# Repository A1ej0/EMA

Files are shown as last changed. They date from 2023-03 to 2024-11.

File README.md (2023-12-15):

<div align="center">

</div>  

# <div align="center">EMA - Estación de Monitoreo Automático 🍃</div>  

<div align="right">
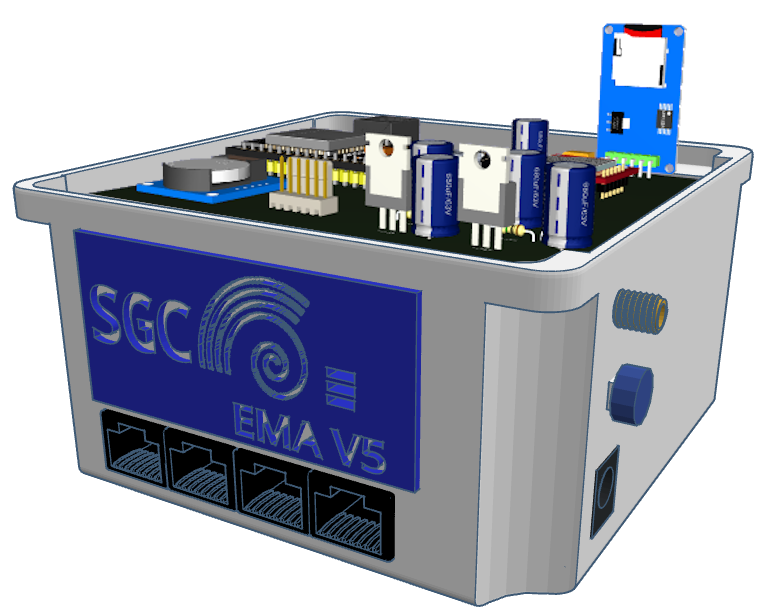
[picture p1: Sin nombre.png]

</div>  

-  De bajo costo💸  

- Enfoque comunitario 🙆🧑‍🎓🧑‍🌾🧑‍🍳🧑‍🚒  

- De alta tecnologia 🚀🛸  

<br/>  

## Que es?  
EMA nace con el objetivo de brindar una alternativa con un sentido social y un enfoque comunitario a dispositivos tecnológicos de alto coste y complejidad, brindando la oportunidad a la comunidad de participar en temas relacionados a la medición de variables medioambientales para el monitoreo de diferentes factores como lluvias, movimientos del suelo, crecimiento de los ríos y calidad de agua. 🌋🏔️🏞️

Todo esto a muy bajo coste y una construcción modular, con partes de muy fácil obtención para promover la participación de todo el mundo 
🌎  

<br/>  

## Que incluye?  
<div align="center">  
<a href="https://pytorch.org/" target="_blank">pytorch</a>  
<a href="https://www.python.org/" target="_blank">Python</a>  
<a href="https://www.cprogramming.com/" target="_blank">C</a>  
<a href="https://www.cplusplus.com/" target="_blank">C++</a>  
<a href="https://www.javascript.com/" target="_blank">JavaScript</a>  
</div>  

El proyecto EMA esta diseñado con un enfoque de codigo abierto y software libre, es por esto que se usaron lenguajes de programacion y aplicativos con este enfoque, para el modulo principal que incluye la placa principal del proyecto (ESP32), se uso micropython, para los sensores externos que requieren un microcontrolador para ser interpretados se uso C++ como codigo de programacion, para la interface web, se hizo uso de Node-red, proyecto de codigo abierto creado por IBM y finalmente Mosquitto como broker de MQTT  

<br/>  

## Características  
- ### Conexión ✨  

📶 Bluetooth, Diseñado para lectura, ajuste y extracción de información desde dispositivos móviles

🥝Wifi, Diseñado para el envió de lecturas de los sensores al servidor del proyecto

📱GPRS, Diseñado para el envió de lectura de sensores mediante una red móvil en caso de ausencia de wifi

📝MicroSD, diseñada para almacenar de forma local lectura de sensores en caso de ausencia de cualquier lectura y como forma de llevar registros

- ### Módulos 🧩  

Los módulos son los sensores que es capaz de leer EMA  

⛈️ Pluviómetro, modulo diseñado para leer los niveles de lluvia en la zona

📏 Distancia, modulo diseñado con ultrasonido para medir distancias de niveles de ríos o similares

🏜️ Temperatura, Modulo diseñado para medir la temperatura medio ambiental

🚄 Aceleración, Modulo diseñado para medir el movimiento de los suelos, montañas, etc

⌛ Reloj, Modulo diseñado para llevar un registro de tiempo del momento de toma de lecturas

💧Calidad de agua, Modulo diseñado para medir el nivel de contaminación de ríos o cuerpos de agua  

- ### Proyección 🚀✨  

Se espera para el futuro la integración de módulos adicionales para lecturas de variables medioambientales diferentes con una variedad mas amplia de sensores, también se pretende el diseño y construcción de un sistema de programación remoto por medio del cual los usuarios podrán cargar el programa en la placa de desarrollo sin requerir ningún programa mas allá de un navegador web 💻  

<br />

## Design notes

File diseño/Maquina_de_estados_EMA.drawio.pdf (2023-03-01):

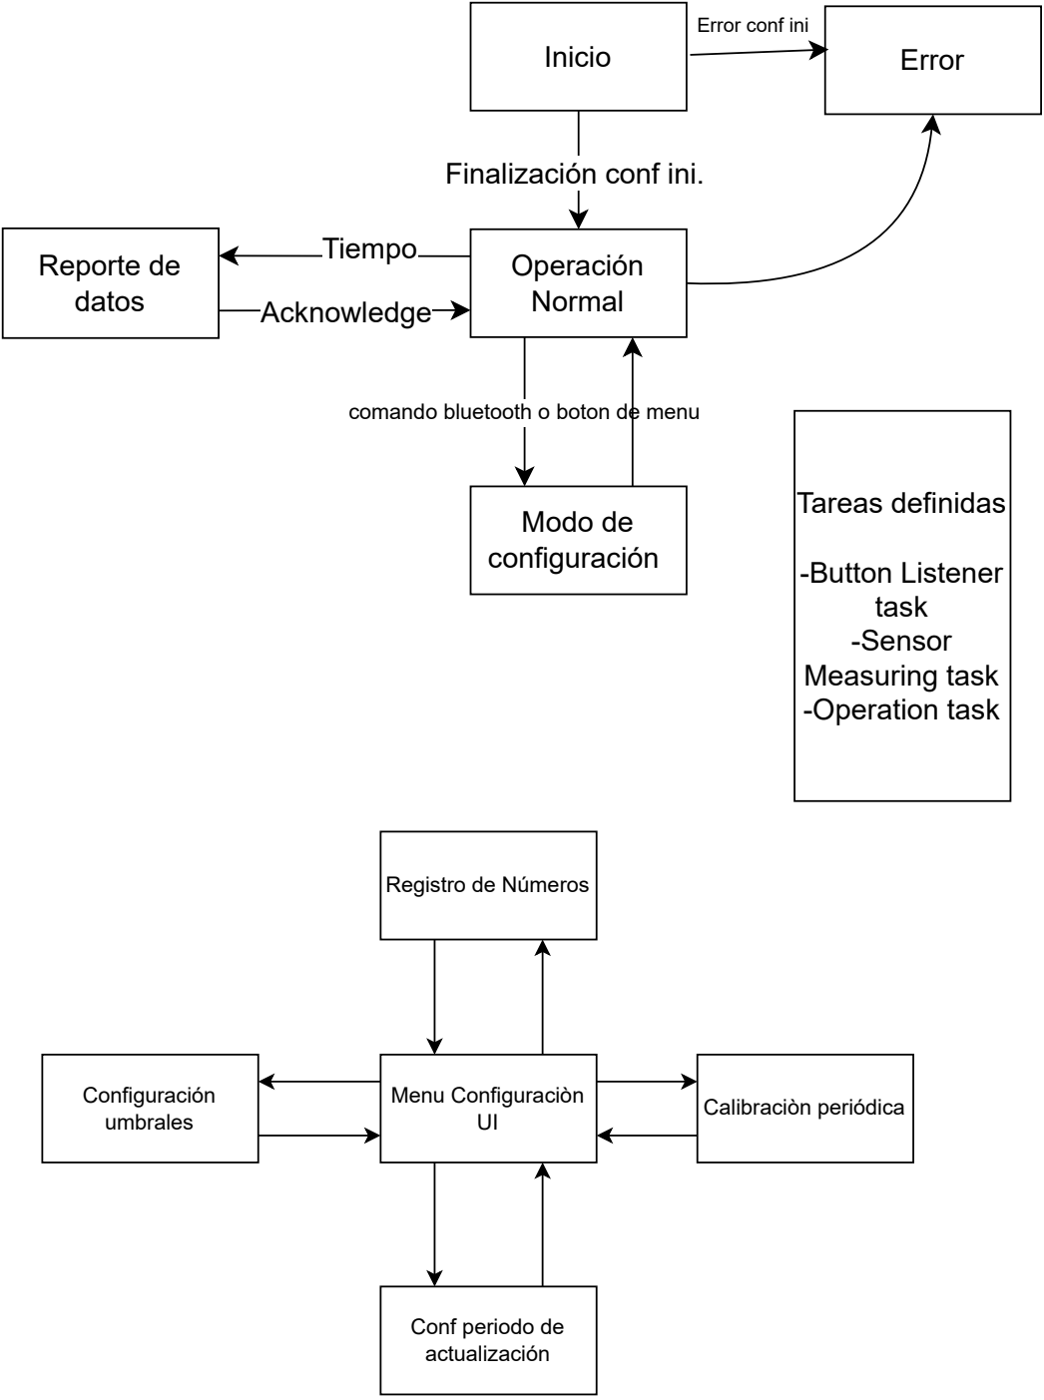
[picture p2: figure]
Inicio; Operación Normal; Finalización conf ini.; Modo de configuración; comando bluetooth o boton de menu; Reporte de datos; Tiempo; Acknowledge; Tareas definidas; -Button Listener task -Sensor Measuring task -Operation task; Error; Error conf ini; Menu Configuraciòn; Calibraciòn periódica Configuración; umbrales; Registro de Números; Conf periodo de actualización

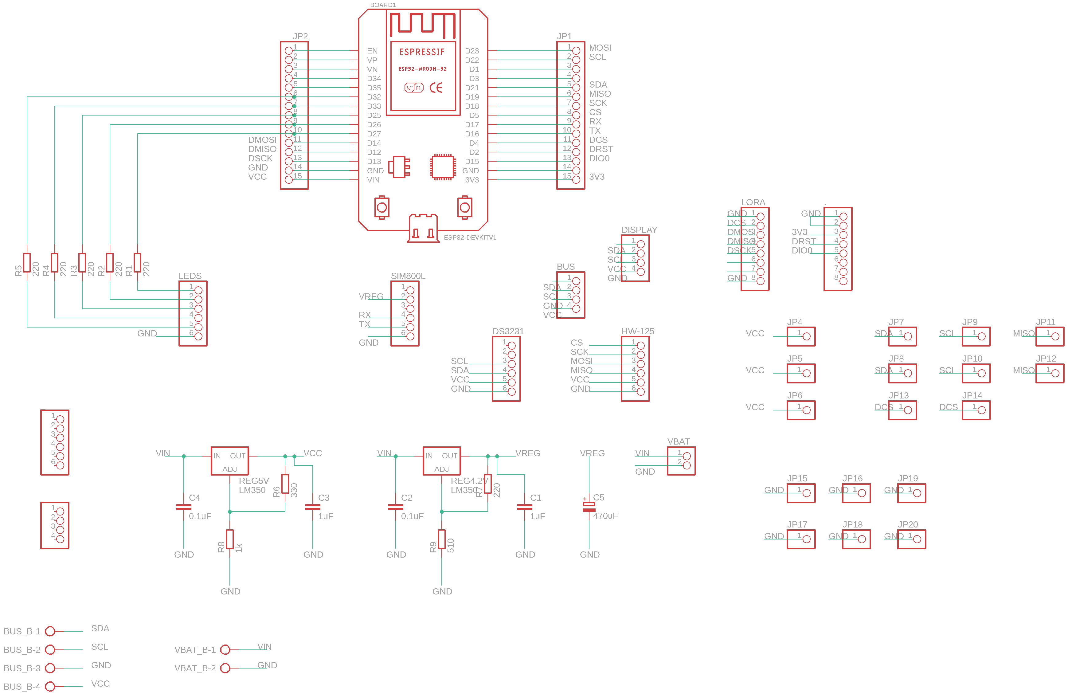
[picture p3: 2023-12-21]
PCB_EMA/EMA_4/schematic.png

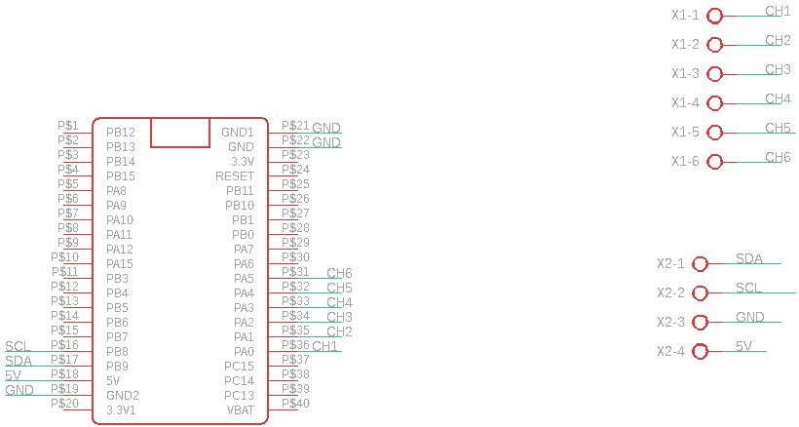
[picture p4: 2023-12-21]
PCB_EMA/EMA_BLUEPILL_MODULE/schematic.png

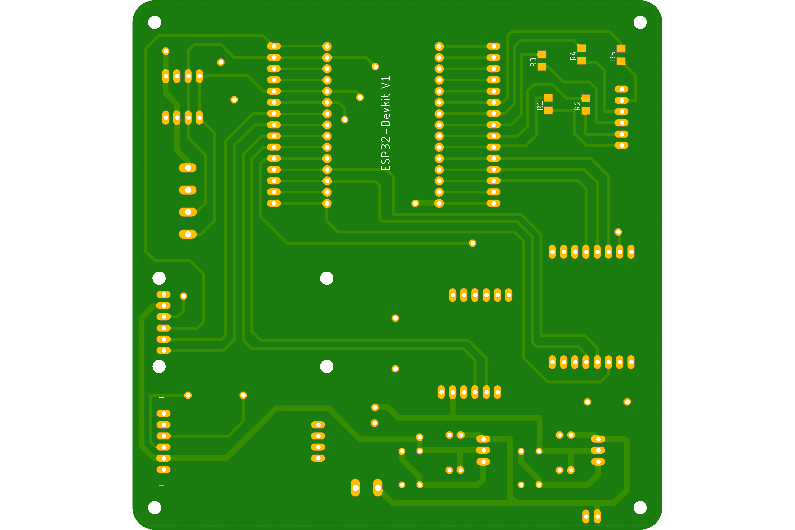
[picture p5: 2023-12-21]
PCB_EMA/EMA_4/board_.png

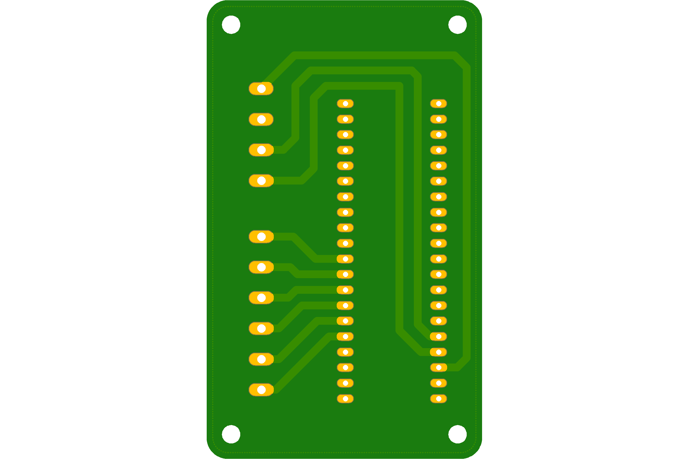
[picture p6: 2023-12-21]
PCB_EMA/EMA_BLUEPILL_MODULE/ema-module2.png

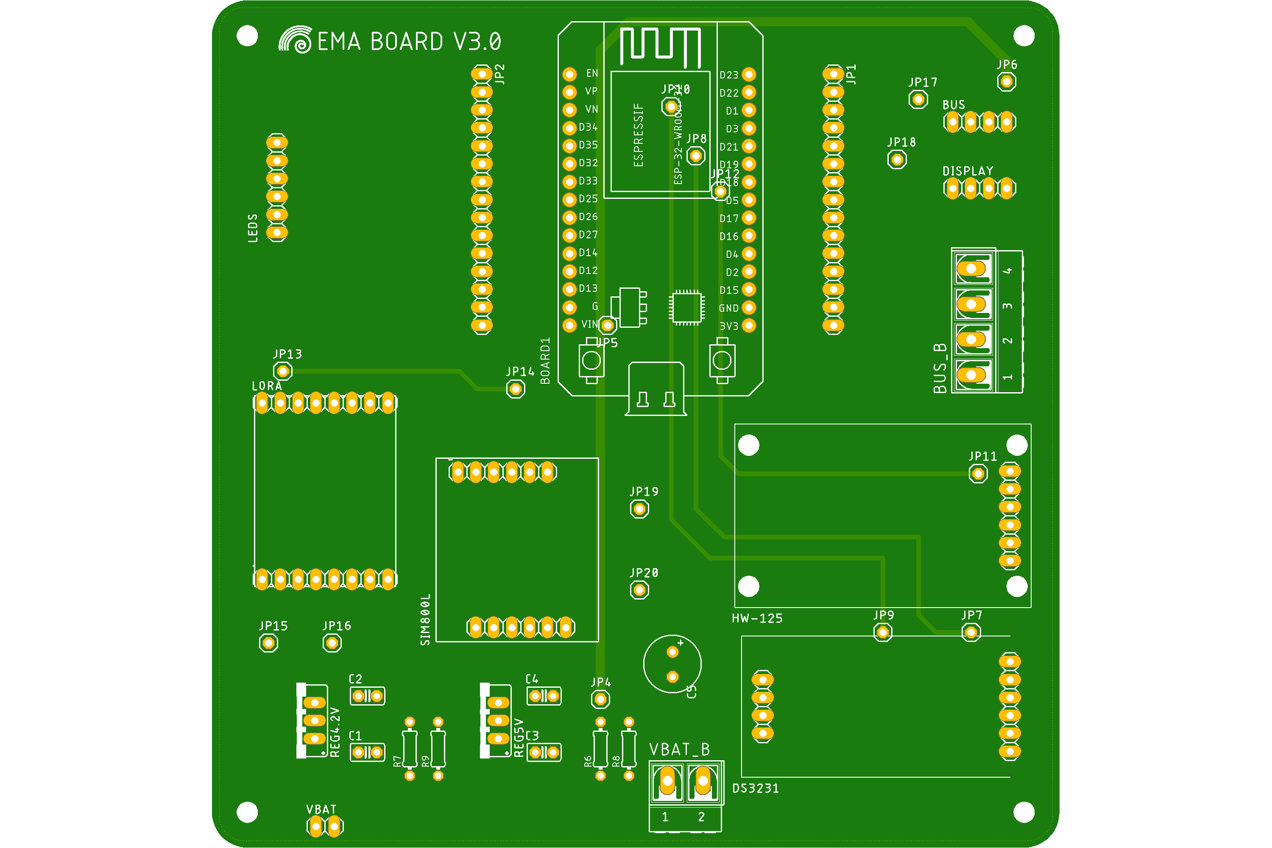
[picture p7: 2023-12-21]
PCB_EMA/EMA_4/board.png

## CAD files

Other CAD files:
Ahorro Sensores/startup.obj
Ahorro Sensores/ahorro.obj

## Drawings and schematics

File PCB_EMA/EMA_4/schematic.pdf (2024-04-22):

3V3_EN | 37 GND | 3*8
VSYS | 39 VBUS | 40 SWDIO 43 | SWGND 42 | SWCLK 41

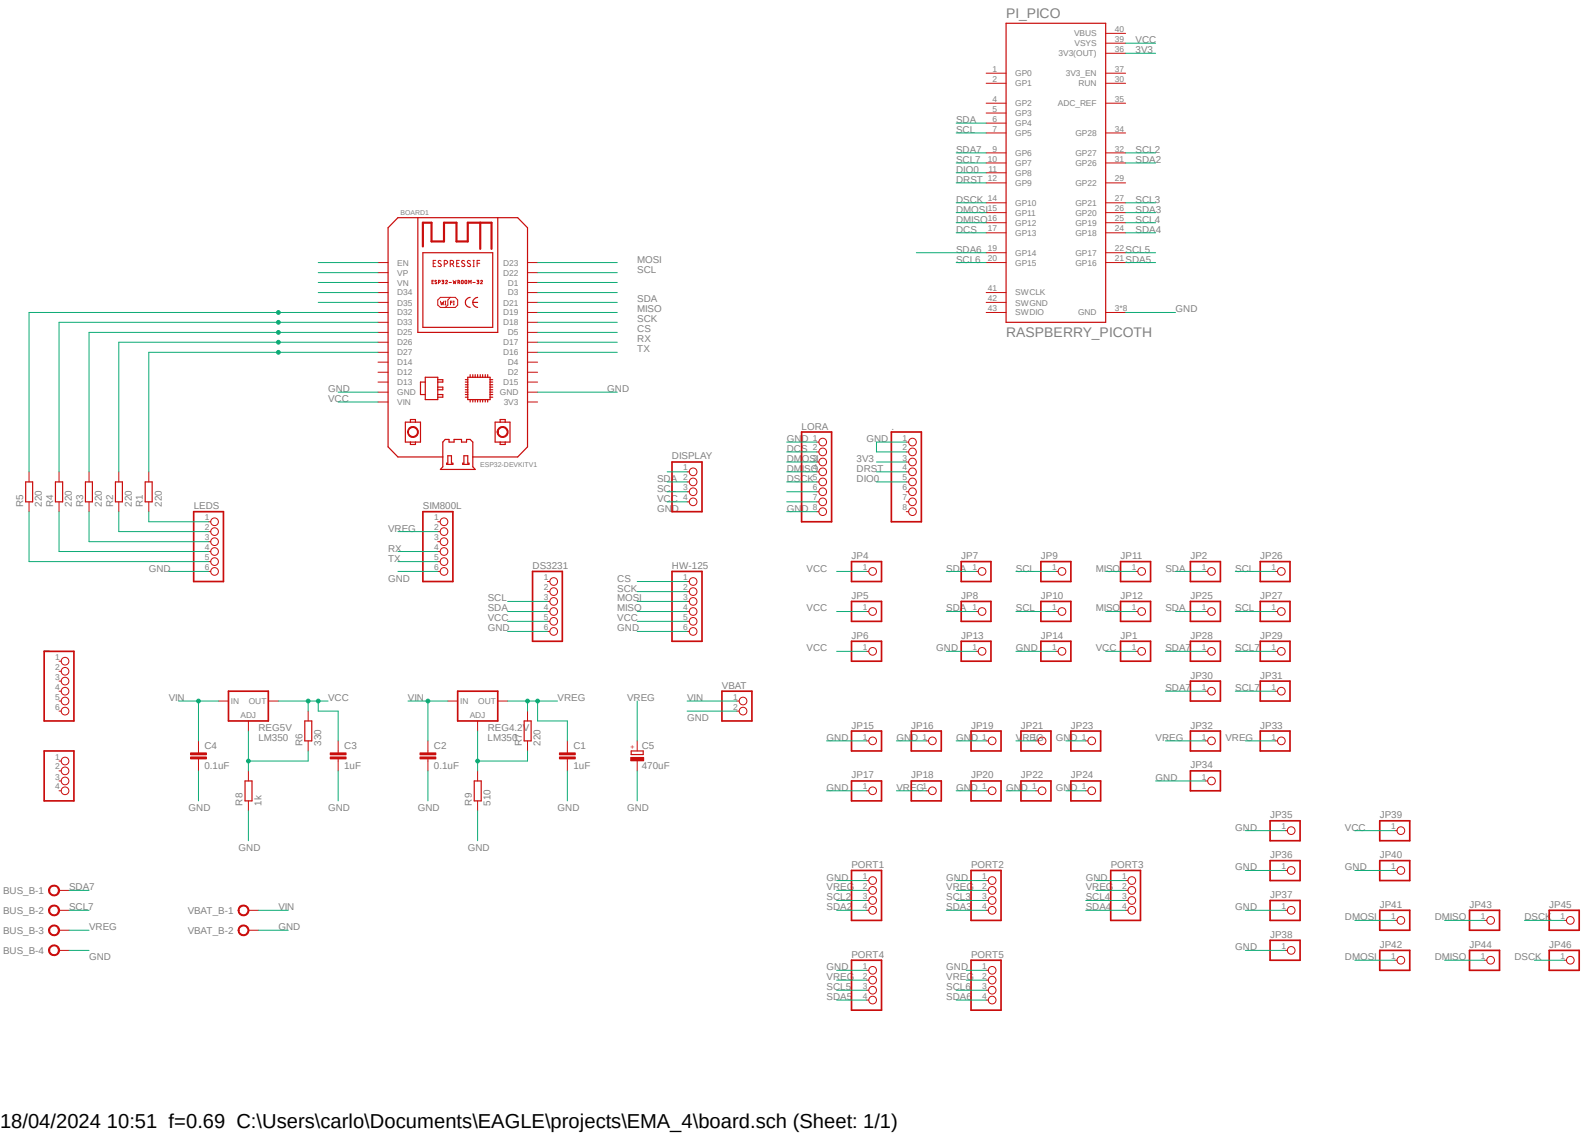
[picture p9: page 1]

18/04/2024 10:51 f=0.69 C:\Users\carlo\Documents\EAGLE\projects\EMA_4\board.sch (Sheet: 1/1)

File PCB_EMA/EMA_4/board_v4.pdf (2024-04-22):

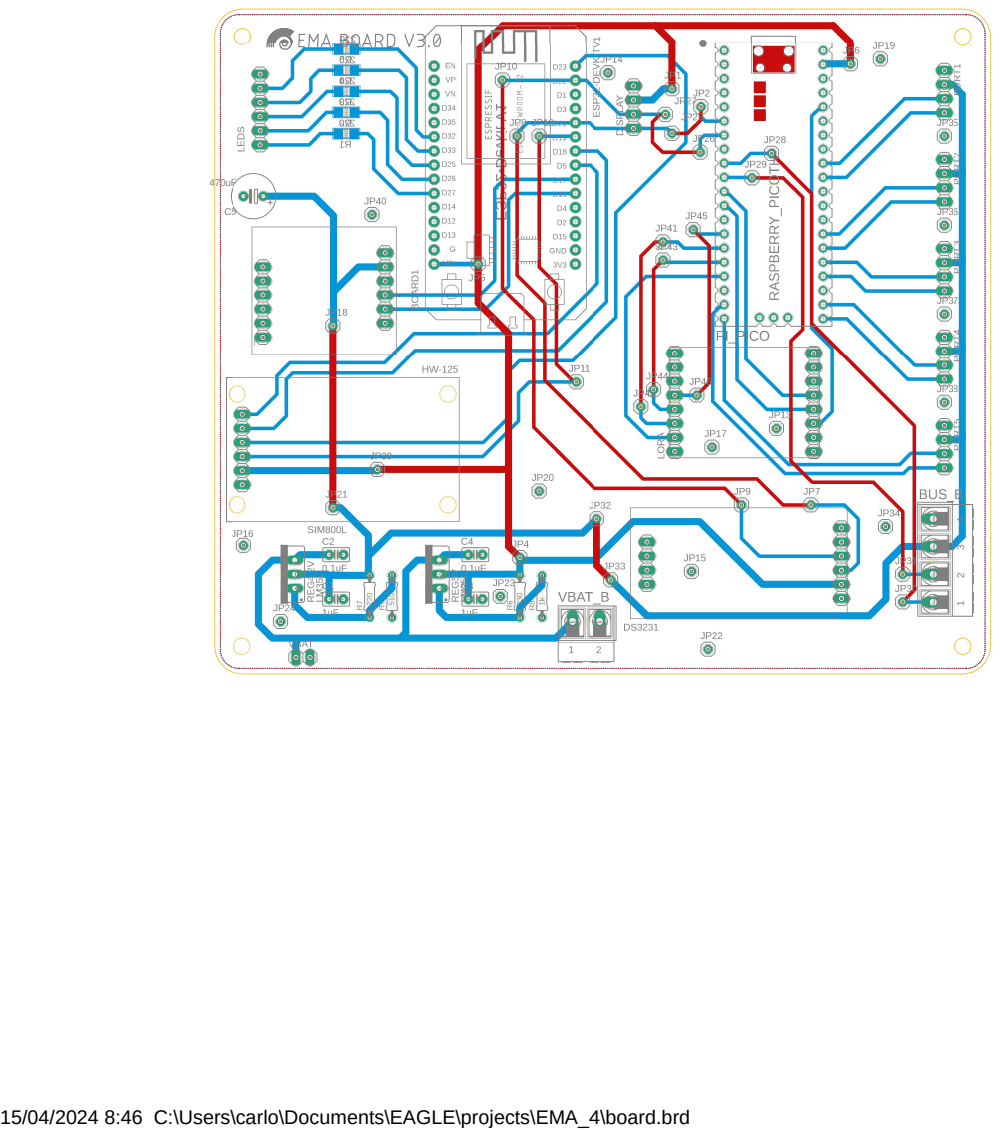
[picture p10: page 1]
PORT1 PORT4 PORT2 PORT5 PORT3

15/04/2024 8:46 C:\Users\carlo\Documents\EAGLE\projects\EMA_4\board.brd

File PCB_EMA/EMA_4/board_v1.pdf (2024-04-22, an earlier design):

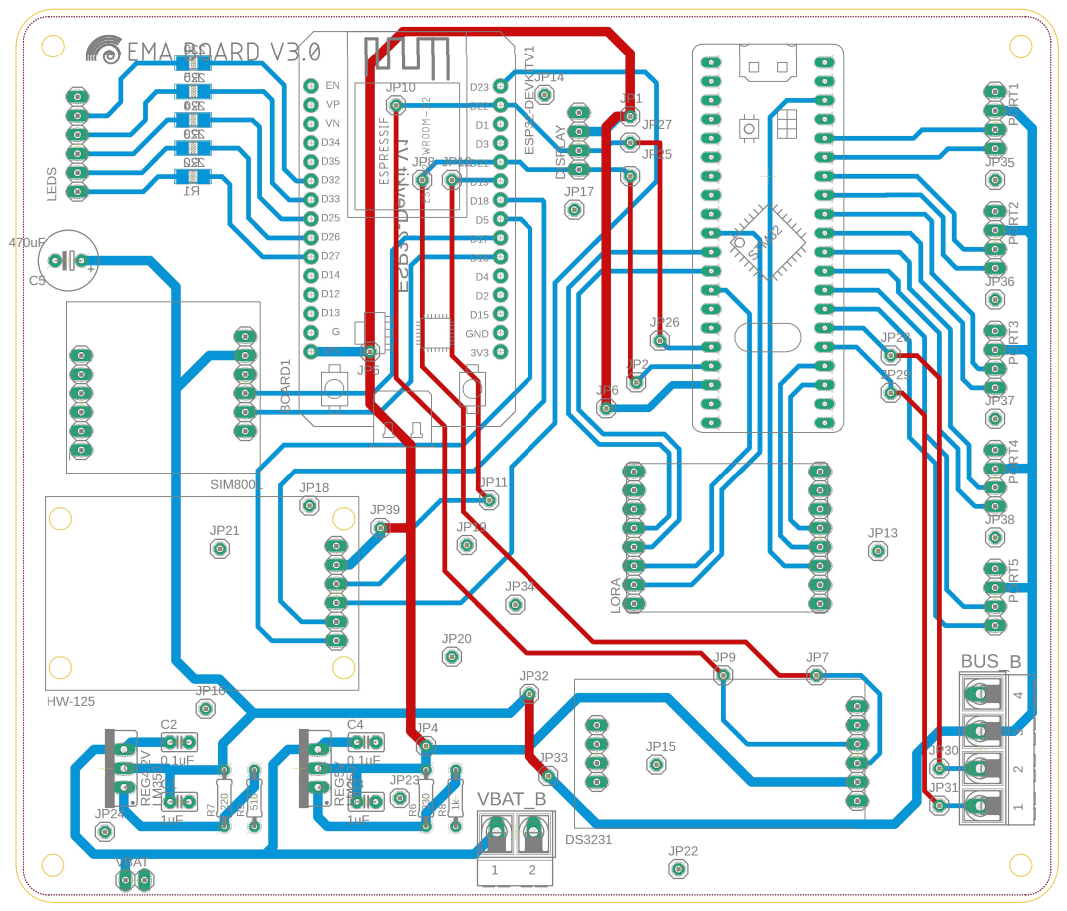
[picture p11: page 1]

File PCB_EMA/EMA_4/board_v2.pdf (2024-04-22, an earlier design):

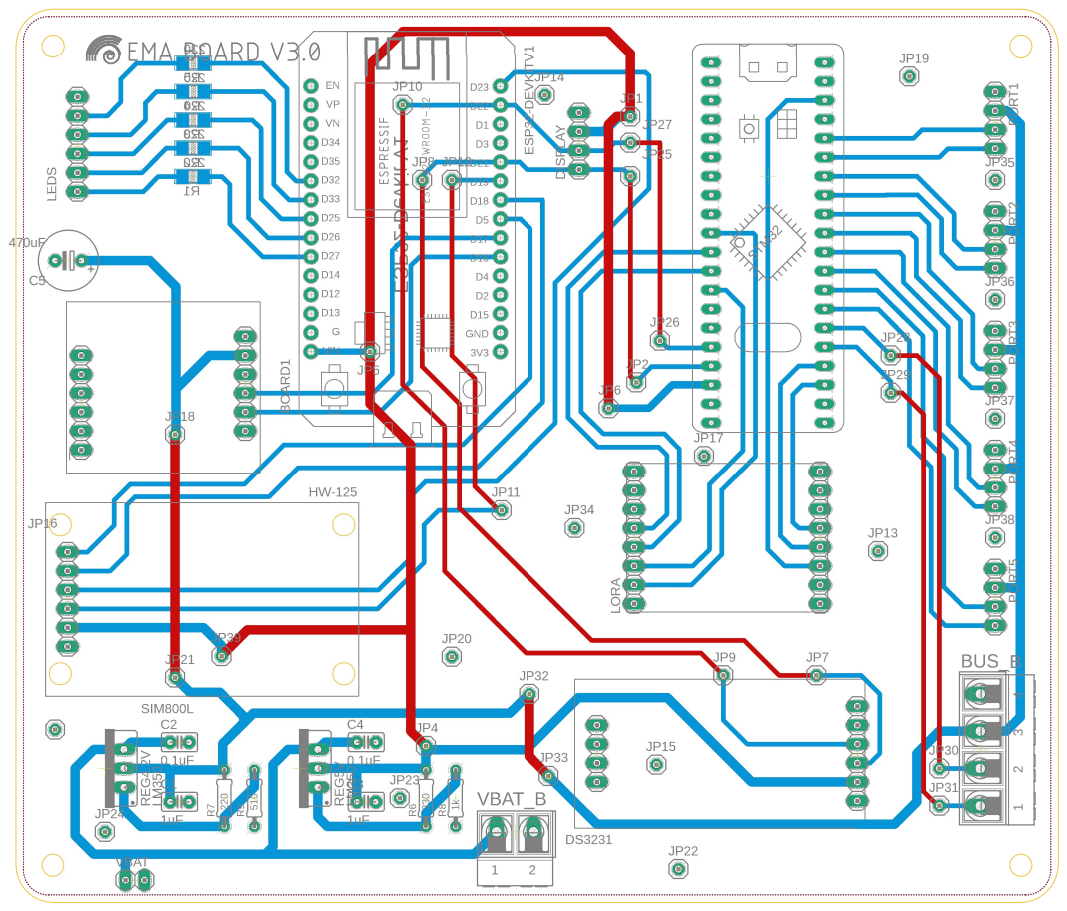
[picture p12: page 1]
PORT1 PORT4 PORT2 PORT5 PORT3

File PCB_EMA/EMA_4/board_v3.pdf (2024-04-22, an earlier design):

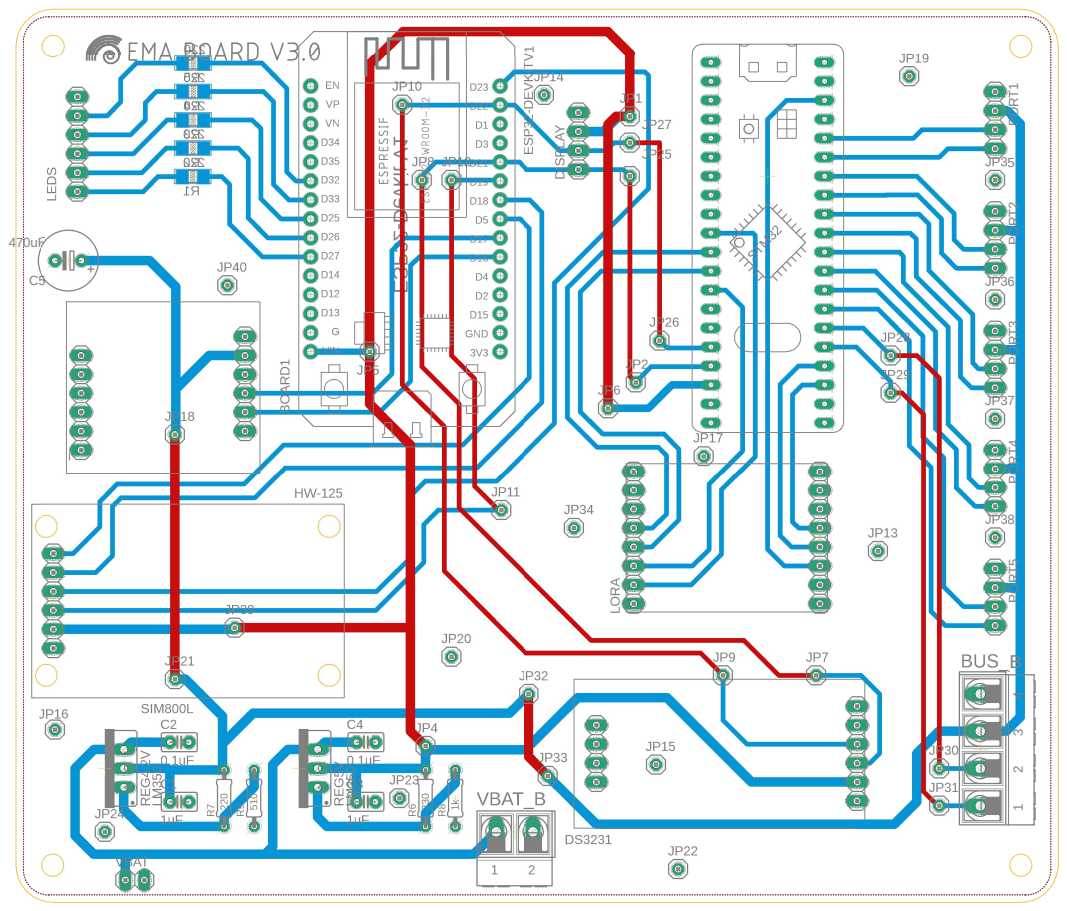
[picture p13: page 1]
PORT1 PORT4 PORT2 PORT5 PORT3

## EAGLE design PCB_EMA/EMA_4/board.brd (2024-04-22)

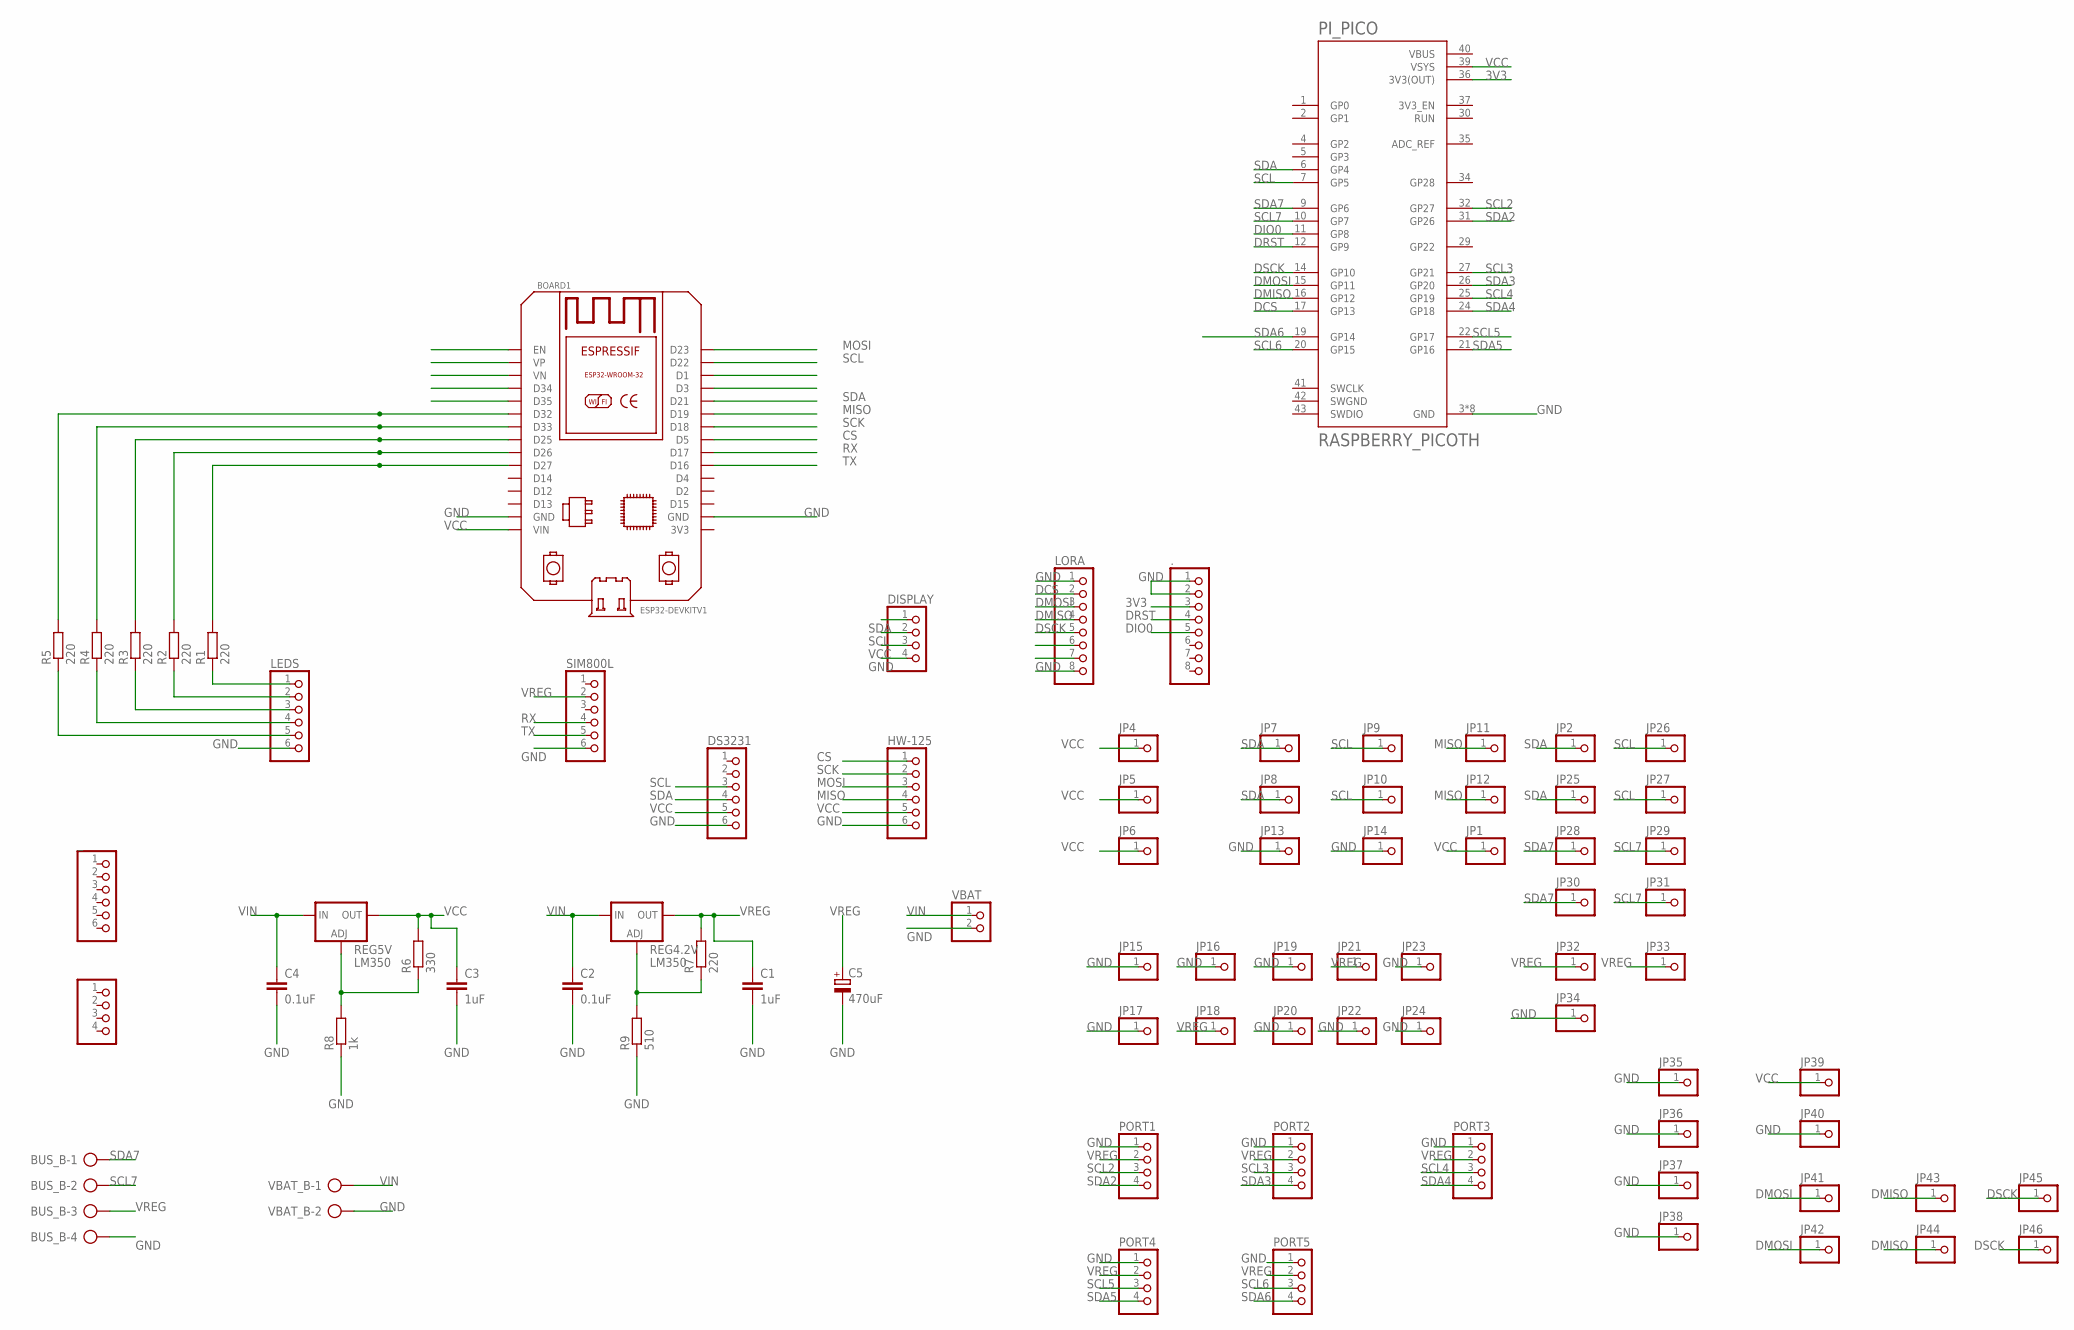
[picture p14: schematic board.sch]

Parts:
.: PINHD-1X8; 1X08
BOARD1: ESP32DEVKITV1; ESP32-DEVKITV1
BUS_B: AK500/4-H
C1, C3: 1uF; C2.5-2
C2, C4: 0.1uF; C2.5-2
C5: 470uF; E3,5-8
DISPLAY: PINHD-1X4; 1X04
DS3231: PINHD-1X6; 1X06
HW-125: PINHD-1X6; 1X06
JP1, JP2, JP4, JP5, JP6, JP7, JP8, JP9, JP10, JP11, JP12, JP13, JP14, JP15, JP16, JP17, JP18, JP19, JP20, JP21, JP22, JP23, JP24, JP25, JP26, JP27, JP28, JP29, JP30, JP31, JP32, JP33, JP34, JP35, JP36, JP37, JP38, JP39, JP40, JP41, JP42, JP43, JP44, JP45, JP46: PINHD-1X1; 1X01
JP3: PINHD-1X4; 1X04
LEDS: PINHD-1X6; 1X06
LORA: PINHD-1X8; 1X08
PI_PICO: RASPBERRY_PICOTH; PICO-PKG-TH
PORT1, PORT2, PORT3, PORT4, PORT5: PINHD-1X4; 1X04
R1, R2, R3, R4, R5: 220; R1206
R6: 330; 0204/7
R7: 220; 0204/7
R8: 1k; 0204/7
R9: 510; 0204/7
REG4.2V, REG5V: LM350; 317TS
SIM800L: PINHD-1X6; 1X06
VBAT: PINHD-1X2; 1X02
VBAT_B: AK500/2-H
_: PINHD-1X6; 1X06

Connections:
3V3: ..3, PI_PICO.36 (3V3(OUT))
CS: BOARD1.D5, HW-125.1
DCS: LORA.2, PI_PICO.17 (GP13)
DIO0: ..5, PI_PICO.11 (GP8)
DMISO: JP43.1, JP44.1, LORA.4, PI_PICO.16 (GP12)
DMOSI: JP41.1, JP42.1, LORA.3, PI_PICO.15 (GP11)
DRST: ..4, PI_PICO.12 (GP9)
DSCK: JP45.1, JP46.1, LORA.5, PI_PICO.14 (GP10)
GND: ..1, ..2, BOARD1.GND, BOARD1.GND@1 (GND), BUS_B.4, C1.2, C2.2, C3.2, C4.2, C5.-, DISPLAY.4, DS3231.6, HW-125.6, JP13.1, JP14.1, JP15.1, JP16.1, JP17.1, JP19.1, JP20.1, JP22.1, JP23.1, JP24.1, JP34.1, JP35.1, JP36.1, JP37.1, JP38.1, JP40.1, LEDS.6, LORA.1, LORA.8, PI_PICO.3 (GND), PI_PICO.8 (GND), PI_PICO.13 (GND), PI_PICO.18 (GND), PI_PICO.23 (GND), PI_PICO.28 (GND), PI_PICO.33 (GND), PI_PICO.38 (GND), PORT1.1, PORT2.1, PORT3.1, PORT4.1, PORT5.1, R8.1, R9.1, SIM800L.6, VBAT.2, VBAT_B.2
MISO: BOARD1.D19, HW-125.4, JP11.1, JP12.1
MOSI: BOARD1.D23, HW-125.3
unnamed: BOARD1.D32, R5.2
unnamed: BOARD1.D33, R4.2
unnamed: BOARD1.D25, R3.2
unnamed: BOARD1.D26, R2.2
unnamed: BOARD1.D27, R1.2
unnamed: LEDS.1, R1.1
unnamed: LEDS.2, R2.1
unnamed: LEDS.3, R3.1
unnamed: LEDS.4, R4.1
unnamed: LEDS.5, R5.1
unnamed: R6.1, R8.2, REG5V.1 (ADJ)
unnamed: R7.1, R9.2, REG4.2V.1 (ADJ)
RX: BOARD1.D17, SIM800L.4
SCK: BOARD1.D18, HW-125.2
SCL: BOARD1.D22, DISPLAY.2, DS3231.3, JP9.1, JP10.1, JP26.1, JP27.1, PI_PICO.7 (GP5)
SCL2: PI_PICO.32 (GP27), PORT1.3
SCL3: PI_PICO.27 (GP21), PORT2.3
SCL4: PI_PICO.25 (GP19), PORT3.3
SCL5: PI_PICO.22 (GP17), PORT4.3
SCL6: PI_PICO.20 (GP15), PORT5.3
SCL7: BUS_B.2, JP29.1, JP31.1, PI_PICO.10 (GP7)
SDA: BOARD1.D21, DISPLAY.1, DS3231.4, JP2.1, JP7.1, JP8.1, JP25.1, PI_PICO.6 (GP4)
SDA2: PI_PICO.31 (GP26), PORT1.4
SDA3: PI_PICO.26 (GP20), PORT2.4
SDA4: PI_PICO.24 (GP18), PORT3.4
SDA5: PI_PICO.21 (GP16), PORT4.4
SDA6: PI_PICO.19 (GP14), PORT5.4
SDA7: BUS_B.1, JP28.1, JP30.1, PI_PICO.9 (GP6)
SWGND: PI_PICO.42 (SWGND)
TX: BOARD1.D16, SIM800L.5
VBUS: PI_PICO.40 (VBUS)
VCC: BOARD1.VIN, C3.1, DISPLAY.3, DS3231.5, HW-125.5, JP1.1, JP4.1, JP5.1, JP6.1, JP39.1, PI_PICO.39 (VSYS), R6.2, REG5V.2 (OUT)
VIN: C2.1, C4.1, REG4.2V.3 (IN), REG5V.3 (IN), VBAT.1, VBAT_B.1
VREG: BUS_B.3, C1.1, C5.+, JP18.1, JP21.1, JP32.1, JP33.1, PORT1.2, PORT2.2, PORT3.2, PORT4.2, PORT5.2, R7.2, REG4.2V.2 (OUT), SIM800L.2

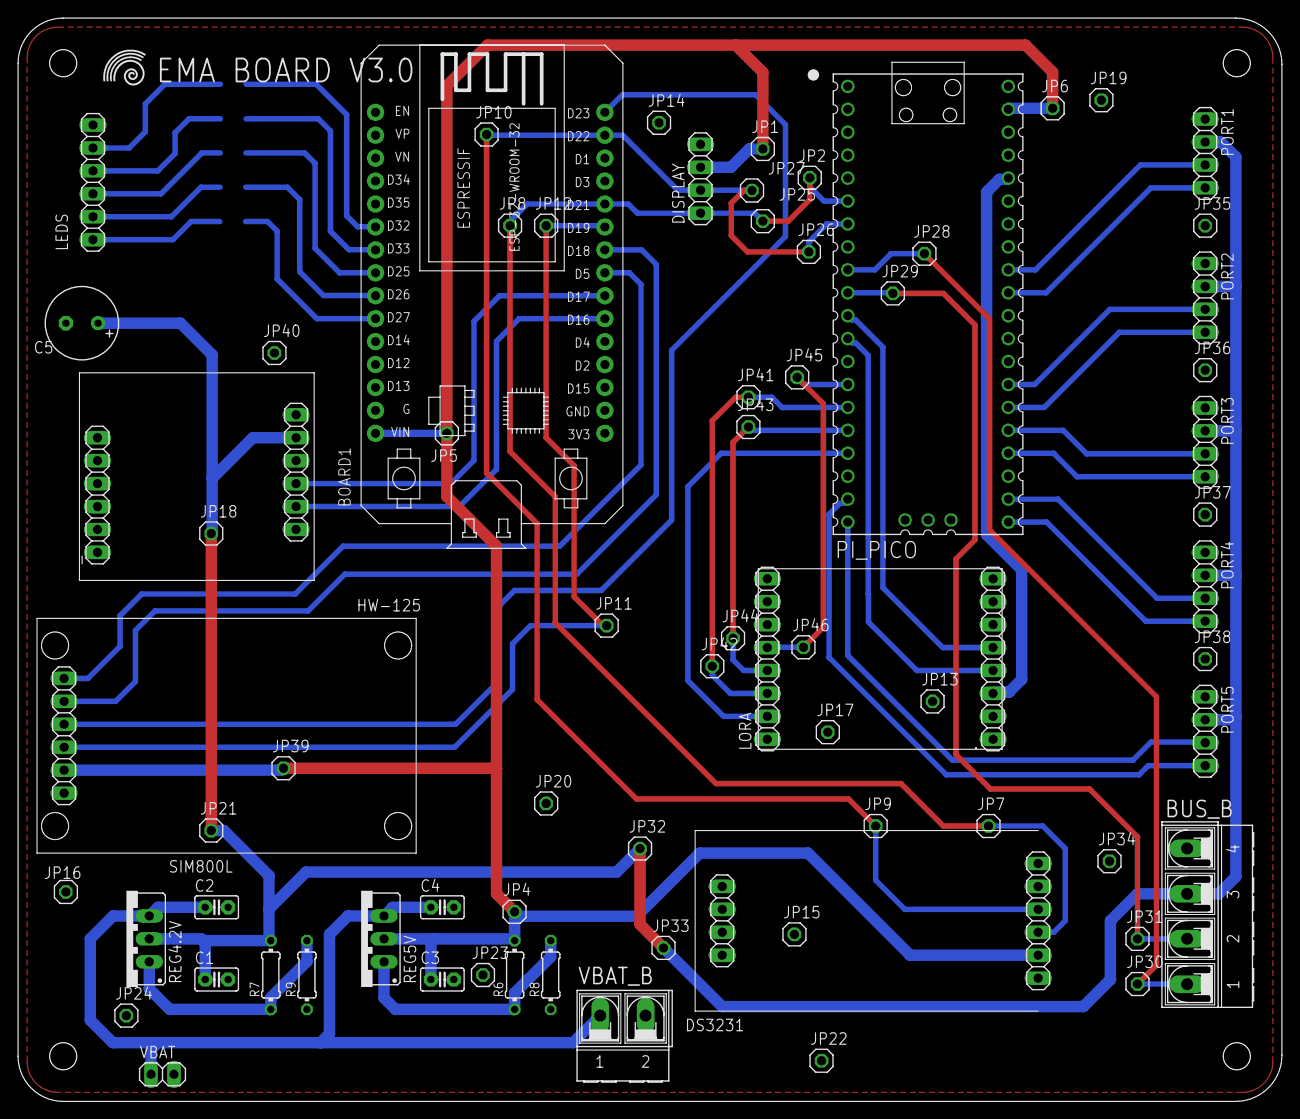
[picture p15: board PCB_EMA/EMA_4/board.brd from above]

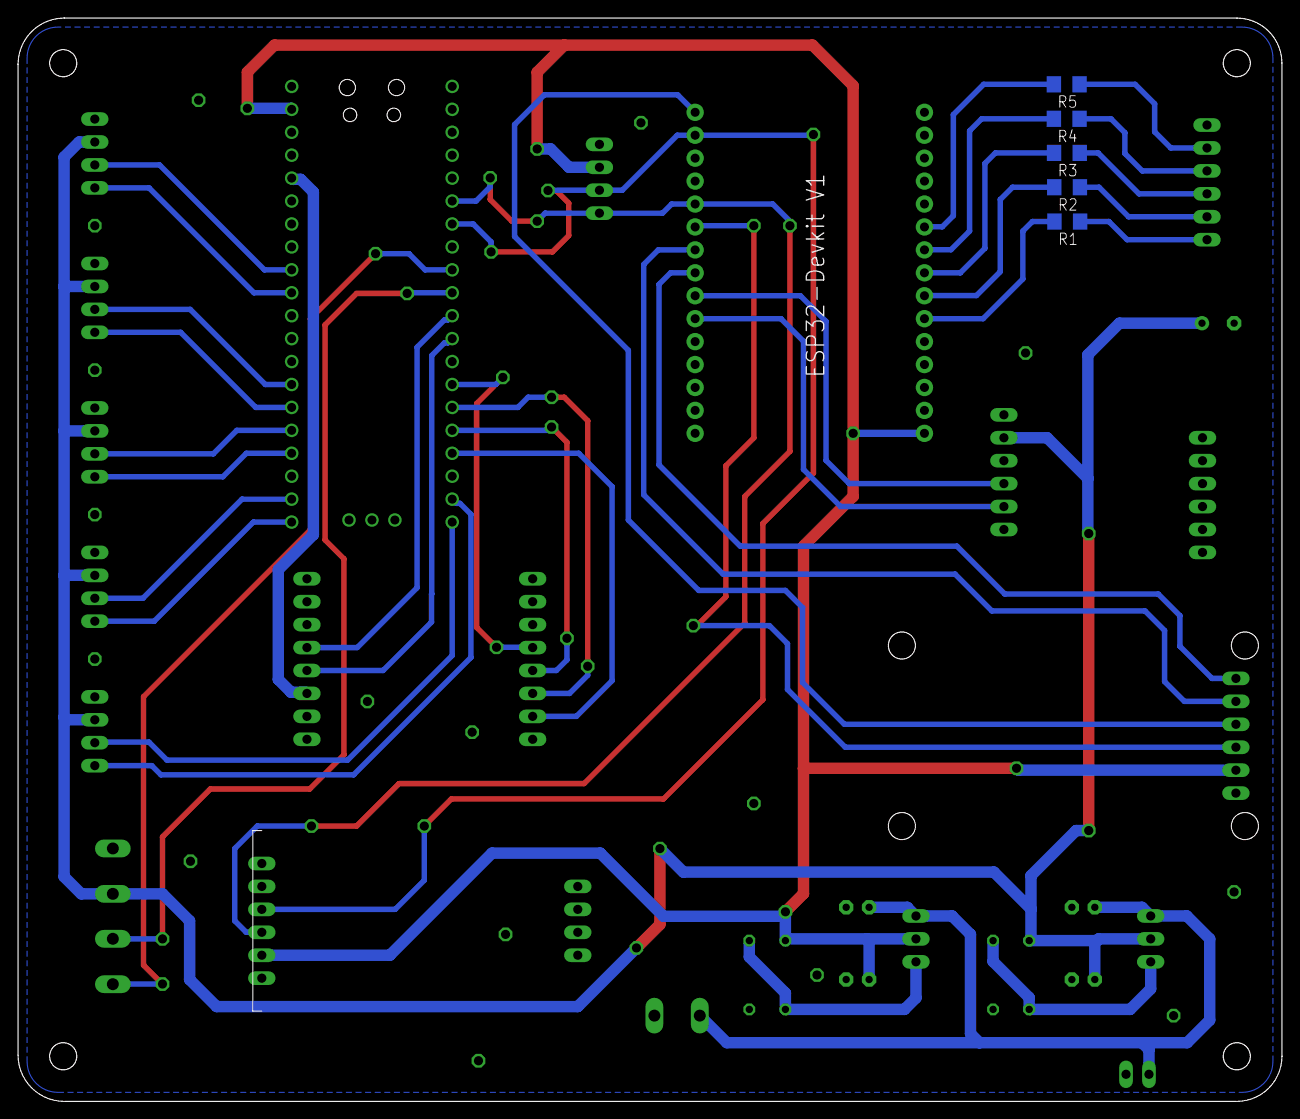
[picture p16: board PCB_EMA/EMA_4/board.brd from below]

Board: 2 copper layers, 140.0 x 120.0 mm, 80 parts (5 on the bottom side), 43 nets.

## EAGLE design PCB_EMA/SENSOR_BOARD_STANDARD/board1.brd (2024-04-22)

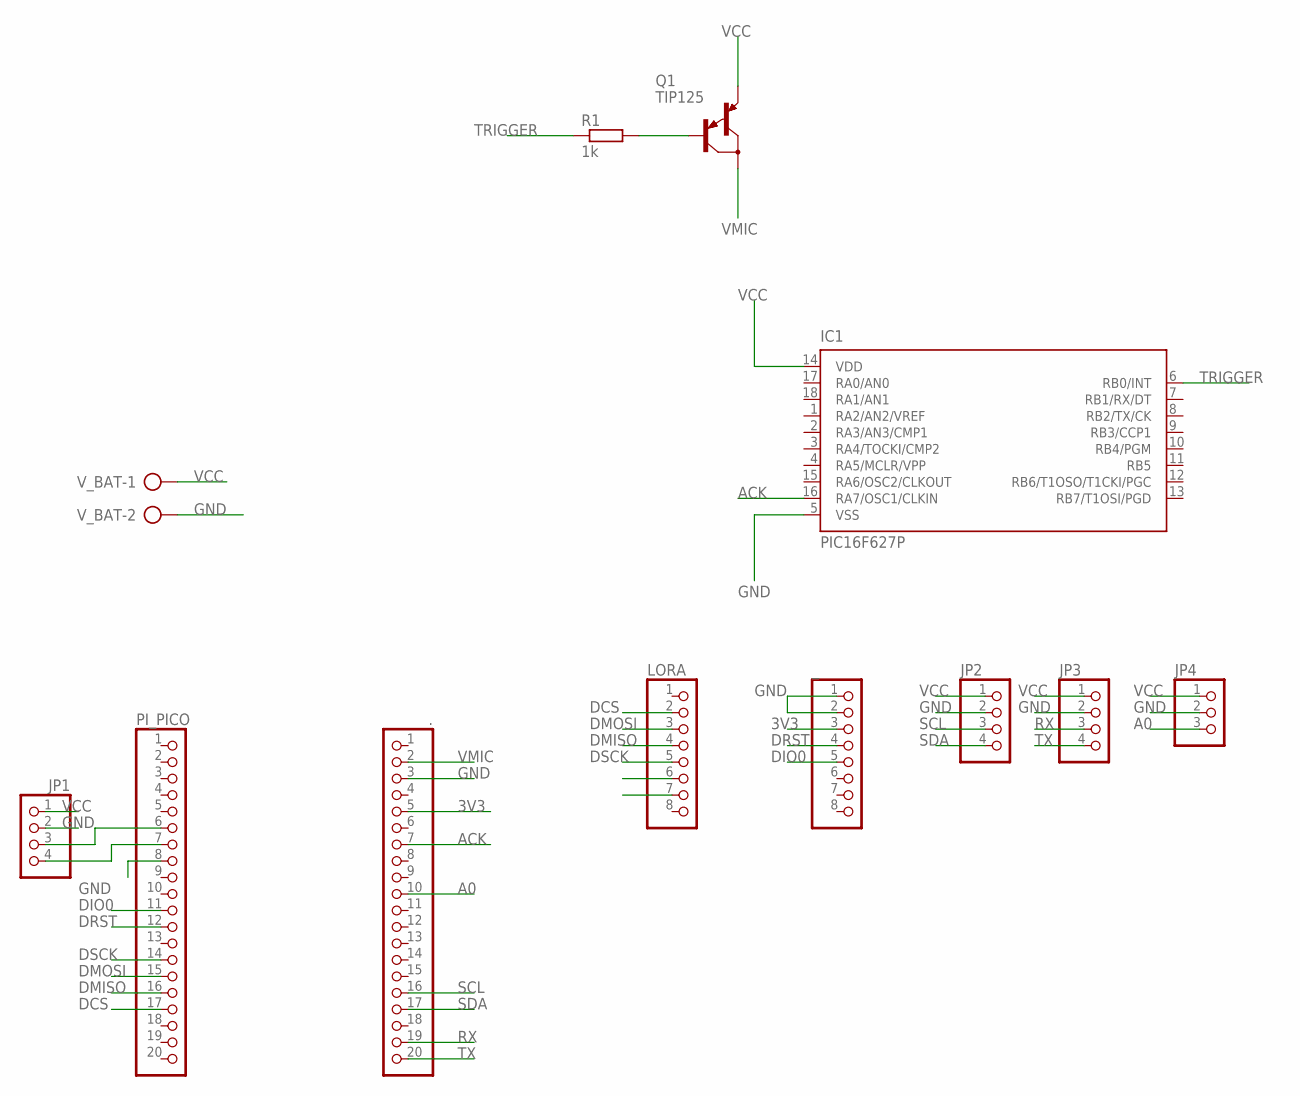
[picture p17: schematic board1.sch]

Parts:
.: PINHD-1X20; 1X20
IC1: PIC16F627P; DIL18
JP1, JP2, JP3: PINHD-1X4; 1X04
JP4: PINHD-1X3; 1X03
LORA: PINHD-1X8; 1X08
PI_PICO: PINHD-1X20; 1X20
Q1: TIP125; TO220
R1: 1k; 0411/15
V_BAT: AK500/2-H
_: PINHD-1X8; 1X08

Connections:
3V3: ..5, _.3
A0: ..10, JP4.3
ACK: ..7, IC1.16 (RA7/OSC1/CLKIN)
DCS: LORA.2, PI_PICO.17
DIO0: PI_PICO.11, _.5
DMISO: LORA.4, PI_PICO.16
DMOSI: LORA.3, PI_PICO.15
DRST: PI_PICO.12, _.4
DSCK: LORA.5, PI_PICO.14
GND: ..3, IC1.5 (VSS), JP1.2, JP2.2, JP3.2, JP4.2, PI_PICO.8, V_BAT.2, _.1, _.2
unnamed: JP1.4, PI_PICO.7
unnamed: JP1.3, PI_PICO.6
unnamed: Q1.1 (B), R1.2
RX: ..19, JP3.3
SCL: ..16, JP2.3
SDA: ..17, JP2.4
TRIGGER: IC1.6 (RB0/INT), R1.1
TX: ..20, JP3.4
VCC: IC1.14 (VDD), JP1.1, JP2.1, JP3.1, JP4.1, Q1.3 (E), V_BAT.1
VMIC: ..2, Q1.2 (C)

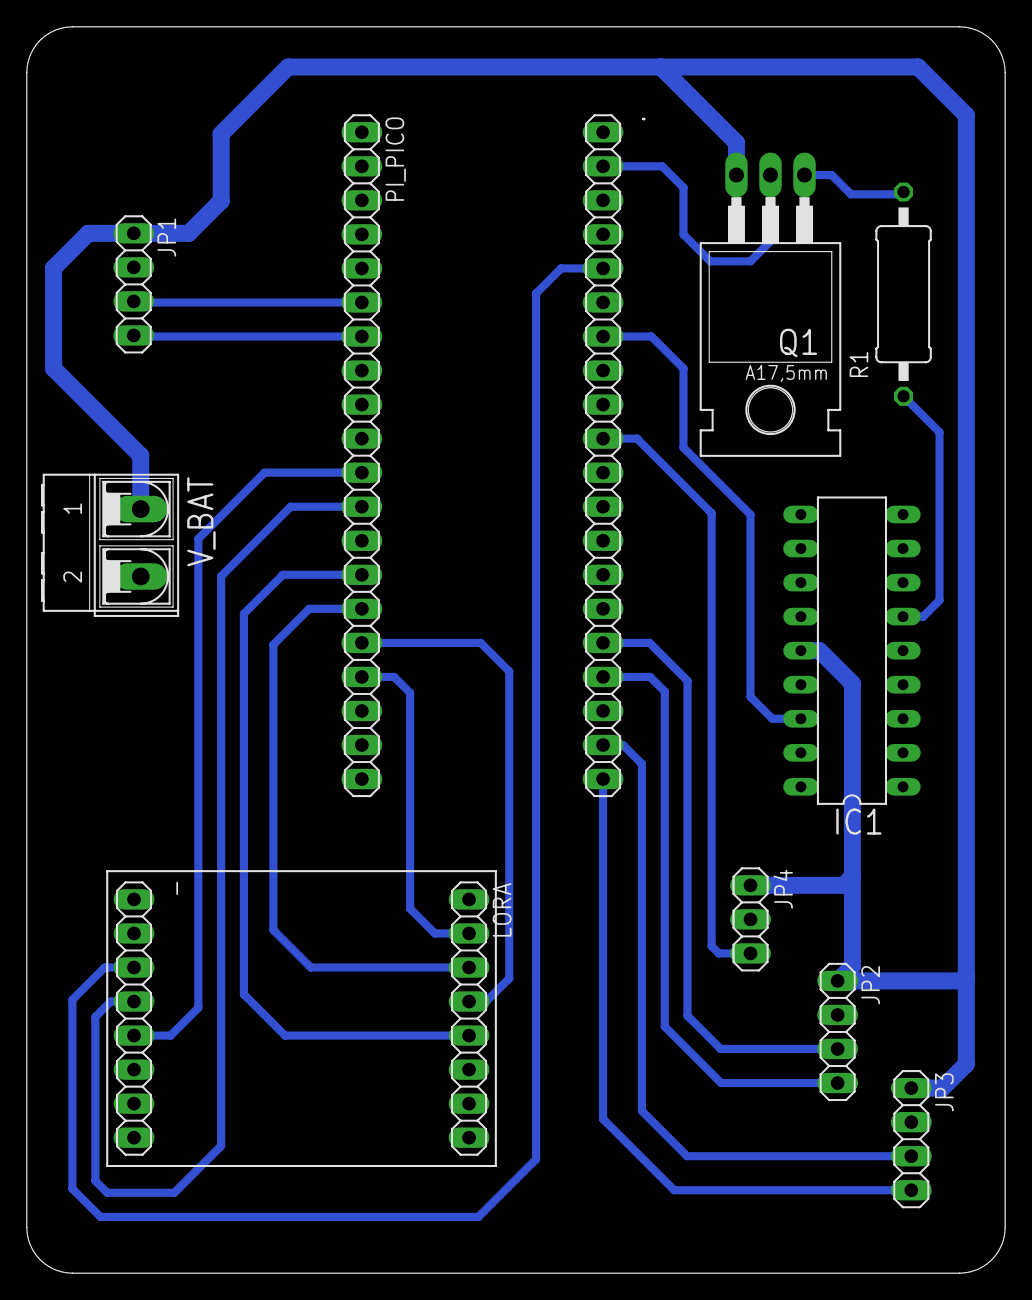
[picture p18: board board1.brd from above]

Board: 2 copper layers, 73.0 x 93.0 mm, 12 parts (0 on the bottom side), 20 nets.

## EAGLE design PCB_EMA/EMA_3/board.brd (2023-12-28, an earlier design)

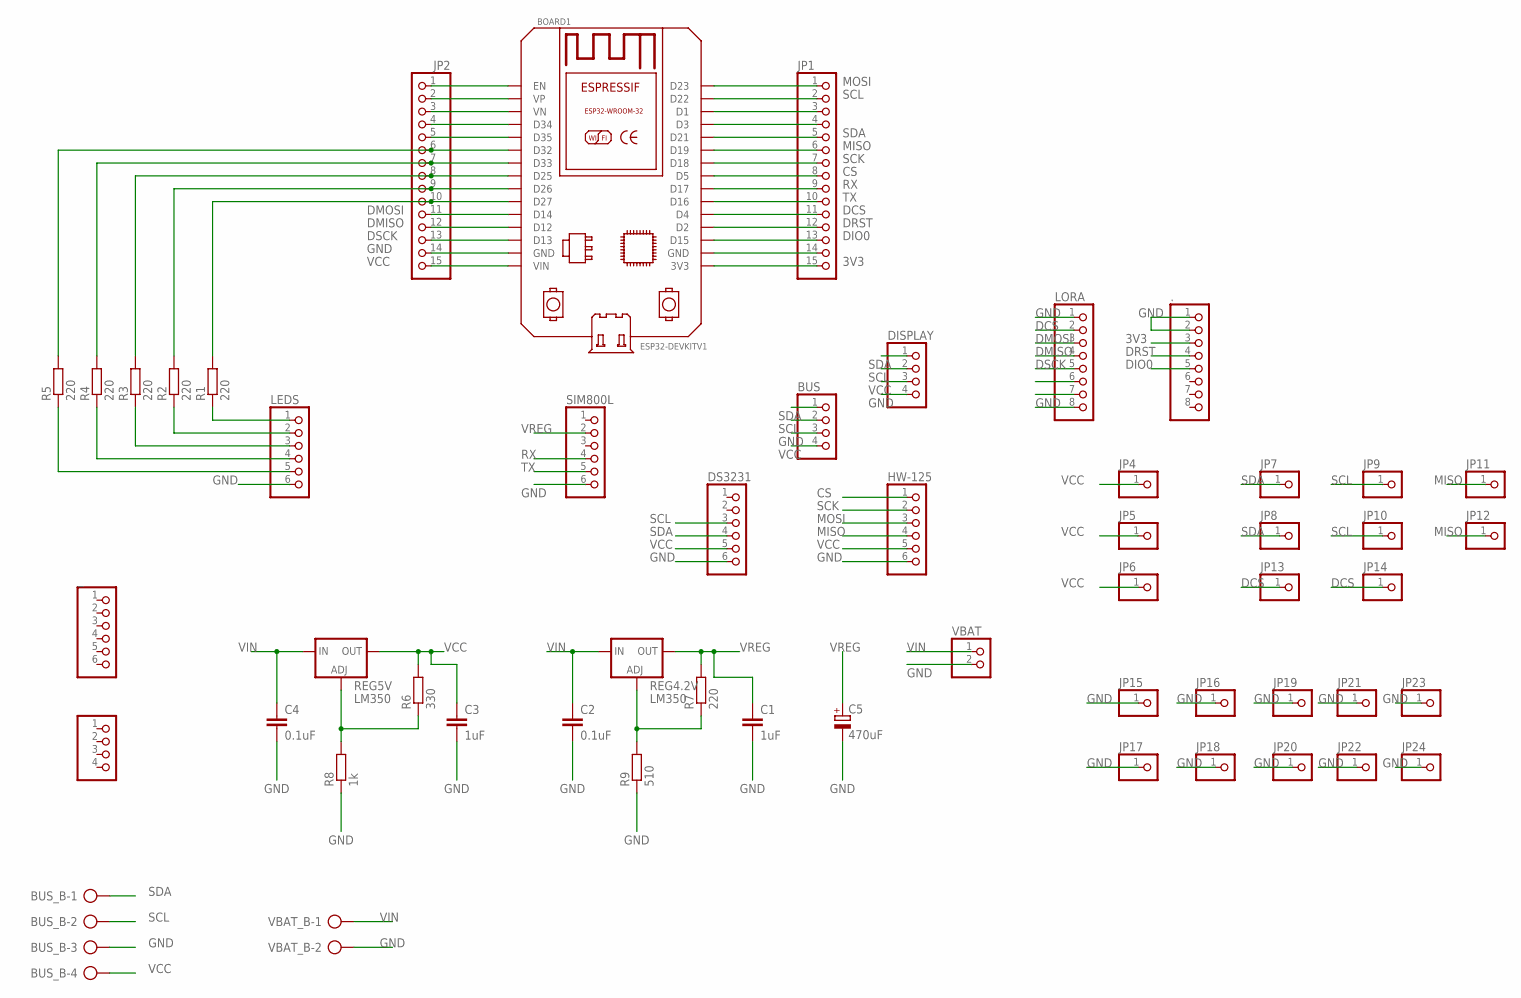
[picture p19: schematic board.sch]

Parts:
.: PINHD-1X8; 1X08
BOARD1: ESP32DEVKITV1; ESP32-DEVKITV1
BUS: PINHD-1X4; 1X04
BUS_B: AK500/4-H
C1, C3: 1uF; C2.5-2
C2, C4: 0.1uF; C2.5-2
C5: 470uF; E3,5-8
DISPLAY: PINHD-1X4; 1X04
DS3231: PINHD-1X6; 1X06
HW-125: PINHD-1X6; 1X06
JP1, JP2: PINHD-1X15; 1X15
JP3: PINHD-1X4; 1X04
JP4, JP5, JP6, JP7, JP8, JP9, JP10, JP11, JP12, JP13, JP14, JP15, JP16, JP17, JP18, JP19, JP20, JP21, JP22, JP23, JP24: PINHD-1X1; 1X01
LEDS: PINHD-1X6; 1X06
LORA: PINHD-1X8; 1X08
R1, R2, R3, R4, R5: 220; R1206
R6: 330; 0204/7
R7: 220; 0204/7
R8: 1k; 0204/7
R9: 510; 0204/7
REG4.2V, REG5V: LM350; 317TS
SIM800L: PINHD-1X6; 1X06
VBAT: PINHD-1X2; 1X02
VBAT_B: AK500/2-H
_: PINHD-1X6; 1X06

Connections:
3V3: ..3, BOARD1.3V3, JP1.15
CS: BOARD1.D5, HW-125.1, JP1.8
DCS: BOARD1.D4, JP1.11, JP13.1, JP14.1, LORA.2
DIO0: ..5, BOARD1.D15, JP1.13
DMISO: BOARD1.D12, JP2.12, LORA.4
DMOSI: BOARD1.D14, JP2.11, LORA.3
DRST: ..4, BOARD1.D2, JP1.12
DSCK: BOARD1.D13, JP2.13, LORA.5
GND: ..1, ..2, BOARD1.GND, BUS.3, BUS_B.3, C1.2, C2.2, C3.2, C4.2, C5.-, DISPLAY.4, DS3231.6, HW-125.6, JP2.14, JP15.1, JP16.1, JP17.1, JP18.1, JP19.1, JP20.1, JP21.1, JP22.1, JP23.1, JP24.1, LEDS.6, LORA.1, LORA.8, R8.1, R9.1, SIM800L.6, VBAT.2, VBAT_B.2
MISO: BOARD1.D19, HW-125.4, JP1.6, JP11.1, JP12.1
MOSI: BOARD1.D23, HW-125.3, JP1.1
unnamed: BOARD1.EN, JP2.1
unnamed: BOARD1.VP, JP2.2
unnamed: BOARD1.VN, JP2.3
unnamed: BOARD1.D34, JP2.4
unnamed: BOARD1.D35, JP2.5
unnamed: BOARD1.D32, JP2.6, R5.2
unnamed: BOARD1.D33, JP2.7, R4.2
unnamed: BOARD1.D25, JP2.8, R3.2
unnamed: BOARD1.D26, JP2.9, R2.2
unnamed: BOARD1.D27, JP2.10, R1.2
unnamed: LEDS.1, R1.1
unnamed: LEDS.2, R2.1
unnamed: LEDS.3, R3.1
unnamed: LEDS.4, R4.1
unnamed: LEDS.5, R5.1
unnamed: BOARD1.D1, JP1.3
unnamed: BOARD1.D3, JP1.4
unnamed: BOARD1.GND@1 (GND), JP1.14
unnamed: R6.1, R8.2, REG5V.1 (ADJ)
unnamed: R7.1, R9.2, REG4.2V.1 (ADJ)
RX: BOARD1.D17, JP1.9, SIM800L.4
SCK: BOARD1.D18, HW-125.2, JP1.7
SCL: BOARD1.D22, BUS.2, BUS_B.2, DISPLAY.2, DS3231.3, JP1.2, JP9.1, JP10.1
SDA: BOARD1.D21, BUS.1, BUS_B.1, DISPLAY.1, DS3231.4, JP1.5, JP7.1, JP8.1
TX: BOARD1.D16, JP1.10, SIM800L.5
VCC: BOARD1.VIN, BUS.4, BUS_B.4, C3.1, DISPLAY.3, DS3231.5, HW-125.5, JP2.15, JP4.1, JP5.1, JP6.1, R6.2, REG5V.2 (OUT)
VIN: C2.1, C4.1, REG4.2V.3 (IN), REG5V.3 (IN), VBAT.1, VBAT_B.1
VREG: C1.1, C5.+, R7.2, REG4.2V.2 (OUT), SIM800L.2

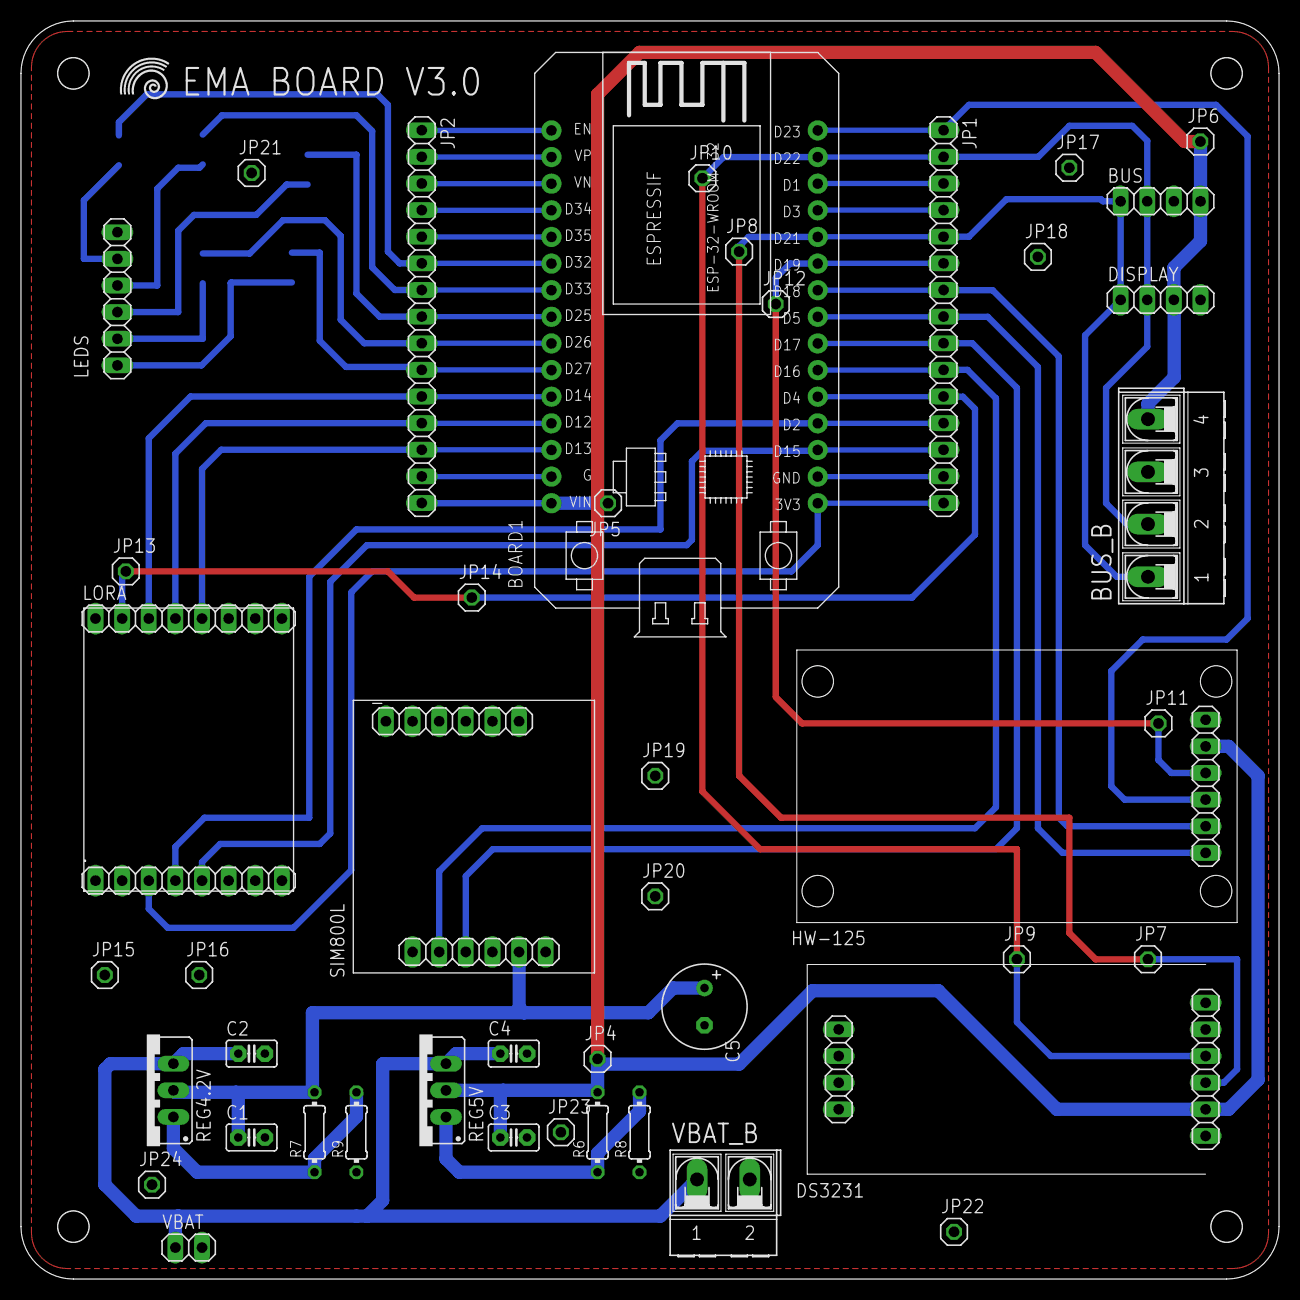
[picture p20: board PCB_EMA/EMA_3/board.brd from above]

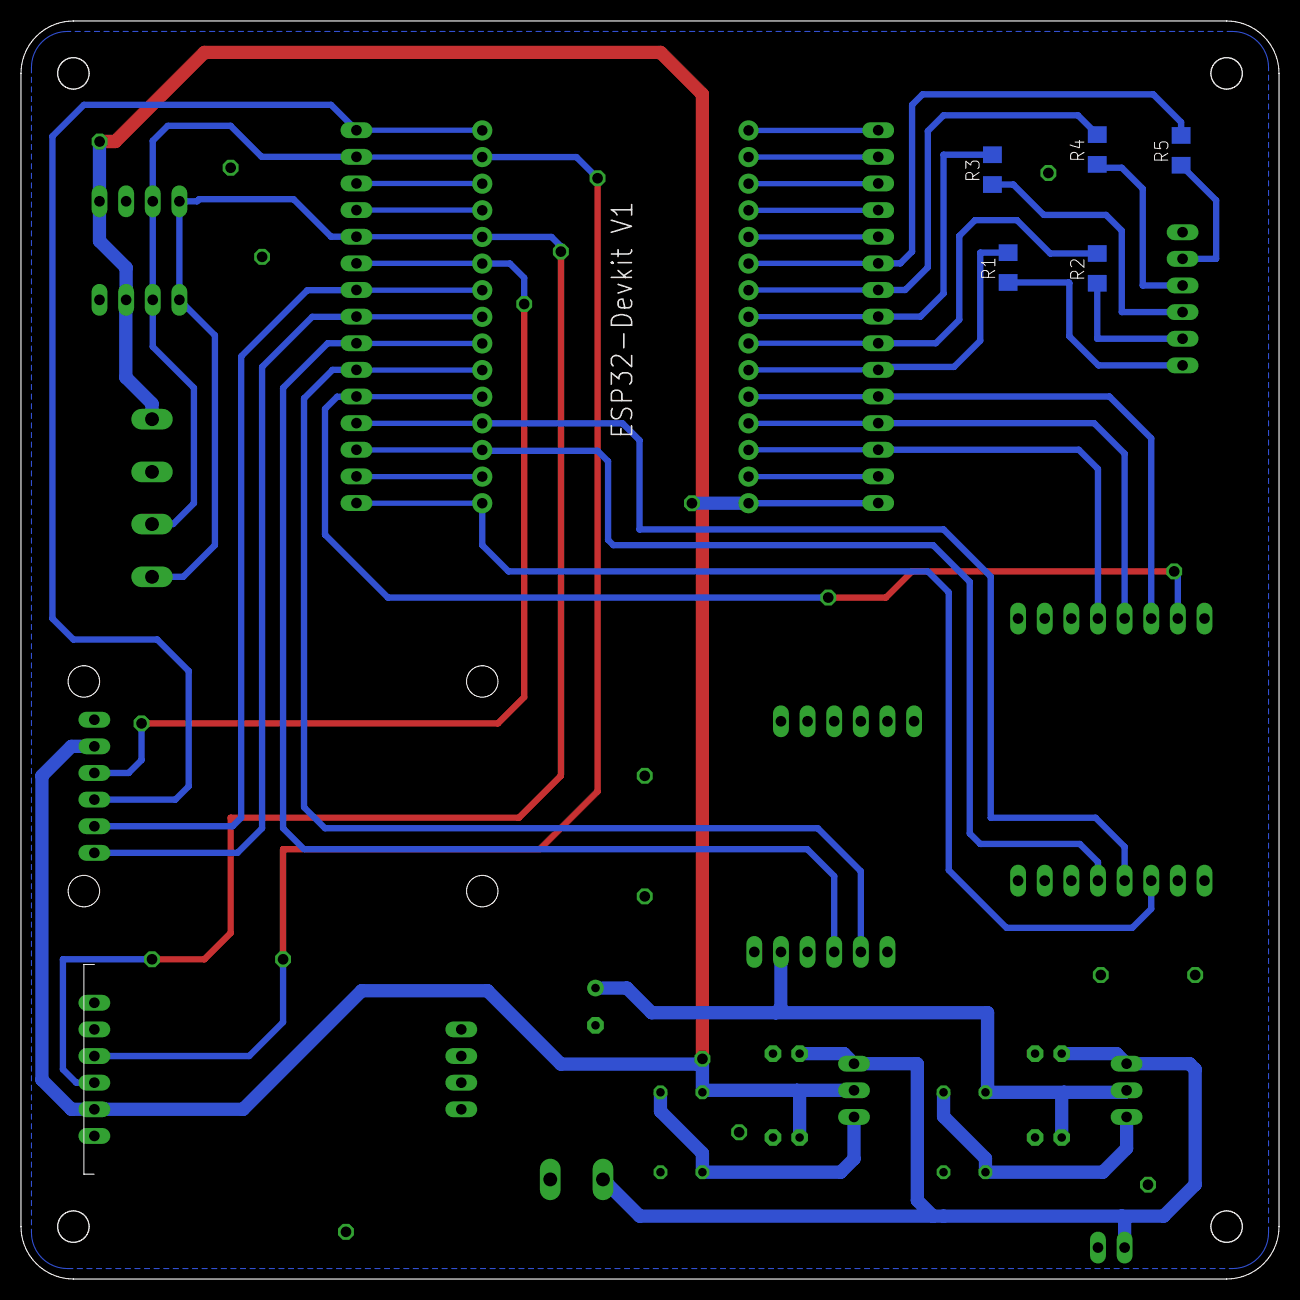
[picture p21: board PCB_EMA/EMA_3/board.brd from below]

Board: 2 copper layers, 120.0 x 120.0 mm, 53 parts (5 on the bottom side), 39 nets.

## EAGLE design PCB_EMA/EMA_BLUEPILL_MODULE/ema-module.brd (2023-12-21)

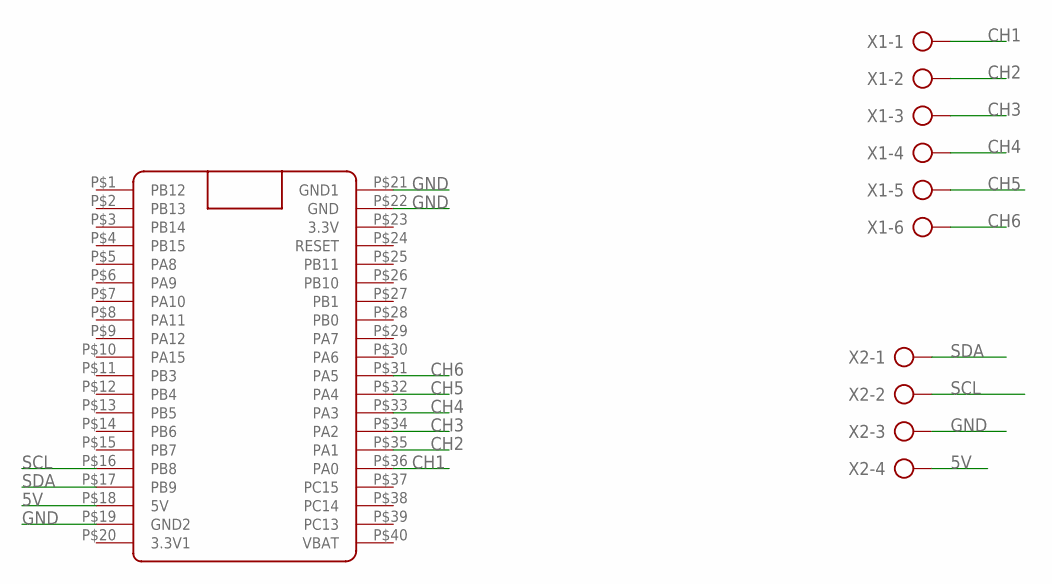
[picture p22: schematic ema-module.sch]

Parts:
U$1: BLUE_PILL
X1: AK500/6-H
X2: AK500/4-H

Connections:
5V: U$1.P$18 (5V), X2.4
CH1: U$1.P$36 (PA0), X1.1
CH2: U$1.P$35 (PA1), X1.2
CH3: U$1.P$34 (PA2), X1.3
CH4: U$1.P$33 (PA3), X1.4
CH5: U$1.P$32 (PA4), X1.5
CH6: U$1.P$31 (PA5), X1.6
GND: U$1.P$19 (GND2), U$1.P$21 (GND1), U$1.P$22 (GND), X2.3
SCL: U$1.P$16 (PB8), X2.2
SDA: U$1.P$17 (PB9), X2.1

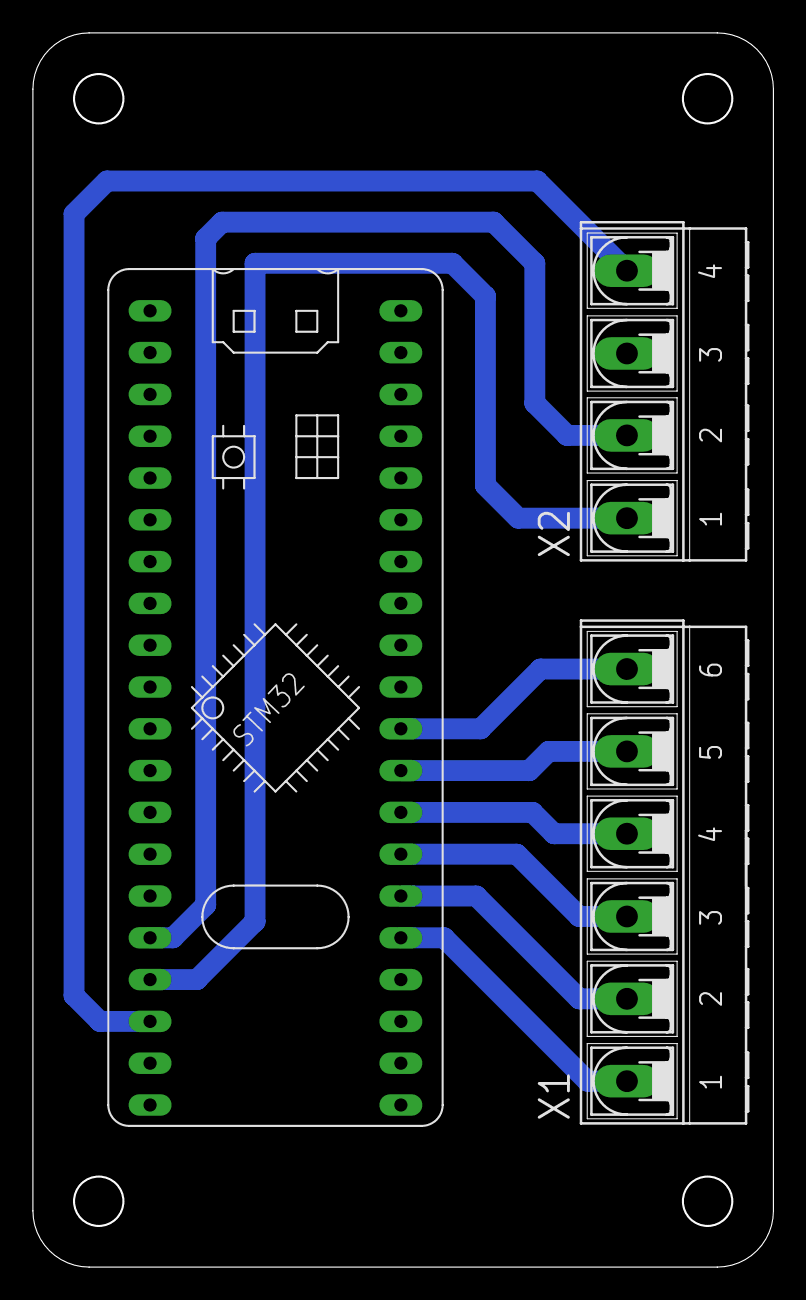
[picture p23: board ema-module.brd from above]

Board: 2 copper layers, 45.0 x 75.0 mm, 3 parts (0 on the bottom side), 10 nets.

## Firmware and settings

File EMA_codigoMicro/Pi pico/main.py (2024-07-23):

import _thread
from machine import SoftI2C, Pin, UART
from i2cslave import i2c_slave
from EMA_Libreria import EMA
from ulora import LoRa, SPIConfig
from machine import WDT
fido = WDT(timeout=8000)  # enable it with a timeout of 2s
fido.feed()


trama = [0] * 10
EMA = EMA()
counter =0
pluvi=0
cadenaA="@00$00#"


led = Pin(25,Pin.OUT)
i2c0 = SoftI2C(scl=Pin(15), sda=Pin(14), freq=400000, timeout=5000)
i2c1 = SoftI2C(scl=Pin(27), sda=Pin(26), freq=400000, timeout=5000)
i2c2 = SoftI2C(scl=Pin(21), sda=Pin(20), freq=400000, timeout=5000)
i2c3 = SoftI2C(scl=Pin(19), sda=Pin(18), freq=400000, timeout=5000)
i2c4 = SoftI2C(scl=Pin(17), sda=Pin(16), freq=400000, timeout=5000)
s_i2c = i2c_slave(0,sda=4,scl=5,slaveAddress=0x41)
canales =[i2c0,i2c1,i2c2,i2c3,i2c4]

flag=False

def on_recv(payload):
    global trama
    try:
        LoRaM=payload.message
        trama[-1]=LoRaM.decode()
    except:
        pass

# Lora Parameters
RFM95_RST = 9
RFM95_SPIBUS = SPIConfig.rp2_1
RFM95_CS = 13
RFM95_INT = 8
RF95_FREQ = 433.0
RF95_POW = 20
SERVER_ADDRESS = 2


lora = LoRa(RFM95_SPIBUS, RFM95_INT, SERVER_ADDRESS, RFM95_CS, reset_pin=RFM95_RST, freq=RF95_FREQ, tx_power=RF95_POW, acks=False)
lora.on_recv = on_recv
lora.set_mode_rx()



def main():
    global trama, cadenaA, canales,pluvi
    while True:
        for canal in canales:
            dispositivos =canal.scan()
            if len(dispositivos)<15:
                for dispositivo in dispositivos:
                    if dispositivo==12:
                        try:
                            magnetrometro=EMA.MPU(canal,2)
                            trama[0] = magnetrometro[0]
                            trama[1] = magnetrometro[1]
                            trama[2] = magnetrometro[2]
                        except:
                            pass

                    elif dispositivo==104:
                        aceleracion=EMA.MPU(canal,0)
                        try:
                            trama[3] = aceleracion[0]
                            trama[4] = aceleracion[1]
                            trama[5] = aceleracion[2]
                        except:
                            pass

                    elif dispositivo==119:
                        temp = EMA.Temperature(canal)
                        if temp ==-1:
                            EMA.calibracionTemp(canal)
                            temp = EMA.Temperature(canal)
                        trama[6] = temp
                        
                    elif dispositivo==42:
                        try:
                            tempor=int(EMA.Pluviometro(canal))
                            pluvi=pluvi+tempor
                            trama[7] = pluvi
                        except:
                            pass
                    elif dispositivo==80:
                        distancia=EMA.distancia(canal)
                        trama[8] = distancia
                    else:
                        pass
        
        try:
            cadena ="$".join(str(valor) for valor in trama)
            cadena ='@'+cadena+'#'
            cadenaA=[ord(c) for c in cadena]
        except:
            pass
_thread.start_new_thread(main,())

while True:
#---------------------------------------------------------------------------------------------------------------------------------------
#LoRa#

    try:
        
        if counter >=len(cadenaA):
            fido.feed()
            counter = 0
            led.value(not led.value())
        if s_i2c.anyRead():
            s_i2c.put(cadenaA[counter] & 0xff)
            counter = counter + 1
        pass
    except:
        pass
        

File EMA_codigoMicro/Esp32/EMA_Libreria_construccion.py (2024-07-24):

##############################################

#Librerias y dependencias
from machine import I2C, Pin
import network,time,os,machine,ds1307,bluetooth,sh1106
from simple import MQTTClient
from BLE import BLEUART
from sim800l import SIM
import framebuf
from random import randint
from ntptime import settime
from ntptime import host as hostntp

##############################################

#Apertura de archivo de ajustes
ajuste = open("ajustes.txt","r")
ajustes=ajuste.readlines()
ajuste.close()

#Variables de ajustes
nombreBluetooth=ajustes[15].strip("\n").split(":")[1]
#print(nombreBluetooth)
wifi=ajustes[10].strip("\n").split(":")[1]
claveWifi=ajustes[11].strip("\n").split(":")[1]
host=ajustes[3].strip("\n").split(":")[1]
server=host
puerto=ajustes[4].strip("\n").split(":")[1]
user=ajustes[5].strip("\n").split(":")[1]
claveMqtt=ajustes[6].strip("\n").split(":")[1]
IPort=""
apn=ajustes[2].strip("\n").split(":")[1]
version=ajustes[23].strip("\n").split(":")[1]
hostntp = "1.europe.pool.ntp.org"

##############################################

miRed = network.WLAN(network.STA_IF)
try:
    miRed.disconnect()
    miRed.active(False)
except:
    pass
miRed.active(True)
miRed.config(dhcp_hostname="EMAV"+str(version)+'-'+str(randint(1,10)))
miRed.config(reconnects=-1)
miRed.config(txpower=9)
try:
    miRed.connect(wifi, claveWifi)
except:
    print('problema wifi')
    pass
#miRed.config(pm=miRed.PM_NONE)
wifiFlag=0

##############################################

config_flag=False

#variables para alerta
#k_value=0.48

#Instancias de objetos
ble=bluetooth.BLE()
buart=BLEUART(ble,nombreBluetooth)

##############################################

#imagenes OLED
with open('images/logo.pbm', 'rb') as f:
    f.readline() # Magic number
    f.readline() # Creator comment
    f.readline() # Dimensions
    data = bytearray(f.read())
#fbuf = framebuf.FrameBuffer(data, 64, 51, framebuf.MONO_HLSB)
fbuf = framebuf.FrameBuffer(data, 64, 51, framebuf.MONO_HLSB)

with open('images/wifiOn.pbm', 'rb') as f:
    f.readline() # Magic number
    f.readline() # Creator comment
    f.readline() # Dimensions
    wifion = bytearray(f.read())
fbufwifion = framebuf.FrameBuffer(wifion, 12, 9, framebuf.MONO_HLSB)

with open('images/btOn.pbm', 'rb') as f:
    f.readline() # Magic number
    f.readline() # Creator comment
    f.readline() # Dimensions
    bton = bytearray(f.read())
fbufbton = framebuf.FrameBuffer(bton, 12, 9, framebuf.MONO_HLSB)

with open('images/gprsOn.pbm', 'rb') as f:
    f.readline() # Magic number
    f.readline() # Creator comment
    f.readline() # Dimensions
    gprson = bytearray(f.read())
fbufgprson = framebuf.FrameBuffer(gprson, 12, 9, framebuf.MONO_HLSB)



with open('images/wifiOff.pbm', 'rb') as f:
    f.readline() # Magic number
    f.readline() # Creator comment
    f.readline() # Dimensions
    wifioff = bytearray(f.read())
fbufwifioff = framebuf.FrameBuffer(wifioff, 12, 9, framebuf.MONO_HLSB)

with open('images/btOff.pbm', 'rb') as f:
    f.readline() # Magic number
    f.readline() # Creator comment
    f.readline() # Dimensions
    btoff = bytearray(f.read())
fbufbtoff = framebuf.FrameBuffer(btoff, 12, 9, framebuf.MONO_HLSB)

with open('images/gprsOff.pbm', 'rb') as f:
    f.readline() # Magic number
    f.readline() # Creator comment
    f.readline() # Dimensions
    gprsoff = bytearray(f.read())
fbufgprsoff = framebuf.FrameBuffer(gprsoff, 12, 9, framebuf.MONO_HLSB)

##############################################
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

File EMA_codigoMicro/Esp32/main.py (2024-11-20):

from EMA_Libreria_sinGSM import EMA
import time
import _thread
import random


time.sleep(1)
EMA = EMA()

datos = [0,0,0,0,0,0,0,0,0,0,0]
textoRaw=""
fecha=0
hora=0
count=0
sensores=0
fechaHora=0
ordTemp=0
frecuencia=1

#Envio de datos mediante wifi
def envioWifiBt():
    global datos,hora,EMA,frecuencia
    while True:
        frecuencia=EMA.frecuenciaDeEnvio()*60
        EMA.envioDatos(datos,hora)
        time.sleep(frecuencia) 
            
_thread.start_new_thread(envioWifiBt,())


def btEnvio():
    global EMA,hora
    while True:
        EMA.envioBt (datos,hora)
        time.sleep(2)
_thread.start_new_thread(btEnvio,())
    

while True:
    fechaHora = EMA.rtc()
    hora=str(fechaHora[4])+":"+str(fechaHora[5])+":"+str(fechaHora[6])
    fecha=str(fechaHora[2])+"/"+str(fechaHora[1])+"/"+str(fechaHora[0])[2:]
    
    try:
        sensores=EMA.sensores()
        sensores=sensores[1:-1]
        sensores=sensores.split("$")
        for i in range(len(sensores)-1):
            if float(sensores[i])!=0:
                datos[i]=sensores[i]
                
    
        if sensores[-1][0]=="D":
            datos[8]=sensores[-1][1:]
        elif sensores[-1][0]=="P":
            if ordTemp != ord(sensores[-1][2]):
                ordTemp = ord(sensores[-1][2])
                datos[7]=str(int(datos[7])+int(sensores[-1][2:]))
                print("Pluv")   
        elif sensores[-1][0]=="Q":
            datos[9]=sensores[-1][1:]
        else:
            pass
    except:
        pass
    
    #test
    #datos[0]=random.randint(0,30)
    #finTest
    if count>=3:
        #lluvia=0.149
        for i in range(len(datos)):
            if textoRaw != "":
                textoRaw=textoRaw+" , "+str(datos[i])
            else:
                textoRaw=str(datos[i])
        #Guardar datos en SD
        EMA.escribirSD(textoRaw)
        textoRaw=""
        count=0
    count=count+1
    time.sleep(5)

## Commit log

2023-03-01 Bluetooth low energy and mpu sensor
2023-03-13 added node-red flows
2023-03-13 corrected node-red flows
2023-03-13 Aplicacion para generar ema.conf
2023-03-13 App para generar conf, version python
2023-03-13 libreria actualizada
    agregado OLED,
    eliminado LCD,
    agregado acelerometro y magnetometro
2023-03-13 Actualizacion menu
    deteccion de sd y archivo de config en la SD
2023-03-13 eliminacion de LCD
    se reemplaza por OLED
2023-03-13 Actualizacion con encoder
2023-03-14 ajustes generales, sensor hall y excepciones
2023-05-15 PCB design added
    [PISO1.brd, PISO1.sch, PISO2sch.brd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]
2023-05-26 Create EMA_AlertaGSM.ino
    Modulo GSM de alerta externo
2023-06-06 BLE actualizado
    Actualizacion, para reemplazar valores reales
2023-07-11 Ema Sensor Actualizado, correccion bugs
2023-07-11 Sensor Calidad Agua
2023-08-29 flujo para envío de archivo de reporte node-red
2023-09-22 Binario sensor conductividad
    para Bluepill, PA_0 = TDS, PA_5=Temperatura.
2023-09-23 librerias sensor conductividad
    para TDS-meter y Termocupla DS1820
2023-11-15 update 15 nov 2023
    [board.brd, board.sch]
2023-12-11 limpieza de archivos obsoletos
2023-12-21 added PCBS and EAGLE filfes
    [PISO1.brd, PISO1.sch, PISO2sch.brd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]
2023-12-26 Actualización flows NodeRed
2023-12-28 update pcb design
2023-12-28 update ema pcb design
    [board.brd, board.sch]
2024-04-10 pi pico
2024-04-16 i2c slave
2024-04-22 added PCB eagle files for v4 and sensor board standard
    [board.brd, board.sch, board1.brd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]
2024-04-26 pdf sensor board
2024-05-15 Actualizacion pi pico
2024-05-24 codigo Ahorro
    [ahorro.obj, startup.obj]
2024-06-05 ultrasonico DF
